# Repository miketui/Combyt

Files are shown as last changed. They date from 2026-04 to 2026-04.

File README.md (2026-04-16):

# TAYLKOMB Modular Comb System — Combyt Repository

**Patent Pending:** USPTO #19362254  
**Principal Engineer / Founder:** Michael David Warren Jr. / TAYLKOMB LLC  
**Active Revision:** Rev D — Vertical Ball-Stud + Cross-Detent Architecture

---

## Repository Structure

```
Combyt/
│
├── scaffold/                    ← 🔧 WORKING CAD PIPELINE (start here)
│   ├── .mcp.json                   MCP server config (Claude Code)
│   ├── pyproject.toml              Python package definition
│   ├── src/taylkomb_mcp/           Server + CAD generation source
│   │   ├── server.py               MCP server (stdio + HTTP)
│   │   ├── server_logic.py         Tool implementations
│   │   ├── spec_models.py          Pydantic spec models (Rev C + D)
│   │   ├── validation.py           Rulepack validation + ranking
│   │   ├── spec_guard.py           Locked datum guard
│   │   ├── cad/
│   │   │   ├── parts.py            Rev D part generators (6 parts)
│   │   │   ├── locking_module.py   Ball-stud + socket geometry
│   │   │   ├── comb_blank.py       Comb silhouette + M-cutout
│   │   │   ├── connector_common.py Shared CAD helpers
│   │   │   ├── combs.py            Phase 2 comb geometry
│   │   │   ├── handles.py          Phase 2 handle geometry
│   │   │   └── assemblies.py       Comb+handle assembly
│   │   └── ...
│   ├── specs/
│   │   ├── taylkomb_revD_master.json    ← ACTIVE SPEC
│   │   ├── taylkomb_revC_master.json    (retired, reference only)
│   │   └── variant_sweeps/
│   │       ├── sweep_A.json             Tight tolerance
│   │       ├── sweep_B.json             Nominal
│   │       └── sweep_C.json             Loose tolerance
│   ├── agent/policies/
│   │   ├── locked_datums.json       NEVER edit without human approval
│   │   └── pass_fail_rules.json     Validation thresholds
│   ├── tests/
│   └── scripts/
│
├── output/                      ← 📦 GENERATED CAD FILES (use these)
│   └── sweep_a/
│       ├── SWEEP_A_SUMMARY.md       Full results report
│       ├── step/                    ← STEP files for manufacturing / CAD import
│       ├── stl/                     ← STL files for 3D printing / preview
│       ├── reports/                 Per-variant markdown reports
│       ├── metrics/                 Measurements + validation JSONs
│       └── release_packs/           Zipped release bundles per variant
│
├── reference/                   ← 📐 ORIGINAL / LEGACY FILES
│   ├── original_cad/
│   │   ├── step/                TC-001 through TH-003 (Rev C originals)
│   │   ├── stl/                 Original mesh exports
│   │   └── pdf/                 (empty, PDFs in docs/)
│   ├── revD_samples/            Early Rev D stem + comb samples
│   └── patches/                 Scaffold + patch zip archives
│
├── docs/                        ← 📄 DOCUMENTATION
│   ├── design_plans/            Rev D plan, PRD, prompts, audits
│   ├── engineering_studies/     Size/weight/ergonomics studies
│   ├── pdfs/                    Per-part drawing PDFs
│   └── images/                  Photos, renders
│
└── README.md                    ← You are here
```

---

## Which files do I use?

### For manufacturing / CAD review
→ **`output/sweep_a/step/`** — these are the latest Rev D STEP files, validated against the rulepack.

| File | Part | OAL | Mass |
|---|---|-----|---|
| `main_comb_A_main_01.step` | Main comb (mixed teeth) | 202 mm | 13.7 g |
| `wide_comb_A_wide_01.step` | Wide-tooth comb | 178 mm | 12.5 g |
| `narrow_comb_A_narrow_01.step` | Narrow-tooth comb | 178 mm | 10.7 g |
| `round_handle_A_round_01.step` | Round tail handle | 165.5 mm | 14.5 g |
| `flat_handle_A_flat_01.step` | Flat handle | 172.5 mm | 30.7 g |
| `double_handle_A_double_01.step` | Double-prong fork | 158 mm | 49.4 g |

### For 3D printing / quick preview
→ **`output/sweep_a/stl/`** — same parts as above, triangulated mesh format.

### For comparison to original designs
→ **`reference/original_cad/step/`** — Rev C originals (TC-001, TC-002, TC-003, TH-001, TH-002, TH-003). **These are retired.**

### When you run a new sweep
New files will appear in `output/sweep_b/`, `output/sweep_c/`, etc. — same subfolder structure.

---

## Quick Start — Run the Pipeline

```bash
cd scaffold
python -m venv .venv && source .venv/bin/activate
pip install -e .

# Verify MCP server
python -m taylkomb_mcp.server --transport stdio

# Or run HTTP for remote access
python -m taylkomb_mcp.server --transport streamable-http --port 3333
```

Then use Claude Code or call the MCP tools directly.

---

## Locked Datums (DO NOT CHANGE without human approval)

| Datum | Value |
|---|---|
| Comb silhouette | 32.0 × 6.7 mm |
| M-cutout | 36.0 peak-to-peak × 18.0 depth |
| Socket | Ø 4.10 × 13.0 mm |
| Stem | Ø 4.00 × 14.0 mm, D-profile chord 3.20 |
| Ball head | Ø 5.00, groove Ø 3.20 |
| Seam step max | 0.10 mm |

---

## Architecture

Rev D: **Vertical ball-stud + spring cross-detent with D-profile anti-rotation.**  
Rev C (horizontal dovetail) is retired.  
Bayonet, collet, magnet variants are ruled out.

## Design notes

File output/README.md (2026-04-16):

# Output — Generated CAD Files

This folder contains CAD files generated by the TAYLKOMB MCP pipeline.  
**Always use files from here** — never from `reference/`.

## Folder Convention

Each sweep gets its own subfolder:

```
output/
├── sweep_a/          ← Tight tolerance (current)
│   ├── step/         ← STEP files — use for manufacturing & CAD import
│   ├── stl/          ← STL files — use for 3D printing & preview
│   ├── reports/      ← Per-variant markdown reports
│   ├── metrics/      ← Measurement + validation JSONs
│   └── release_packs/← Zipped bundles (STEP+STL+report+metrics)
├── sweep_b/          ← Nominal tolerance (future)
└── sweep_c/          ← Loose tolerance (future)
```

## File Naming

Format: `{part_name}_{variant_id}.{ext}`

Example: `main_comb_A_main_01.step`
- Part: `main_comb`
- Sweep: `A` (tight)
- Variant number: `01`

## Which file to use?

| If you need... | Use this |
|---|---|
| Import into Fusion/SolidWorks/FreeCAD | `step/*.step` |
| 3D print a test piece | `stl/*.stl` |
| Check if a variant passed validation | `metrics/*_validation.json` |
| See bounding box / mass / dimensions | `metrics/*_metrics.json` |
| Human-readable summary | `reports/*_report.md` |
| Send everything to a manufacturer | `release_packs/*_release.zip` |

## Current Sweep A Results (6/6 PASS)

See `SWEEP_A_SUMMARY.md` for full details.

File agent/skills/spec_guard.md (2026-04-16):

# Skill — Spec Guard

Purpose:
Protect TAYLKOMB locked datums and system invariants.

Rules:
- Treat `locked_datums` as non-editable.
- Reject requests that change the connector standard unless the spec explicitly unlocks them.
- Always compare proposed overrides against the master spec before geometry generation.

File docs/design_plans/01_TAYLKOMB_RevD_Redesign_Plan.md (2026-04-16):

# TAYLKOMB — Rev D CAD Redesign Plan
**Locking Mechanism Overhaul + Six-Part Geometry — grounded in new render intent + 2026 pro-comb benchmarks**
Michael David Warren Jr. / TAYLKOMB LLC — Patent Pending USPTO #19362254
Date: April 16, 2026

---

## 0. Why this is Rev D (not Rev C)

Rev C assumed a **horizontal dovetail** — the handle slid onto the comb's side like a tongue-and-groove. The new renders (`Black_Combs.png`, `Metal_Agents.png`) + the new STL files you uploaded this session show a fundamentally different architecture:

1. **The Main Comb is the receiver.** It has the carved "M-shaped" dorsal cutout on its spine and **no downward stem**.
2. **The other 5 parts (2 combs + 3 handles) each carry the male stem** that inserts into the Main Comb. This is visible in the renders — Narrow and Wide combs have a thin stem extending *down* from their lower corner; all three handles have a small connector block with a thin pin above it.
3. **Insertion axis is vertical (along the comb's long axis), not lateral.** The stem slides into a socket cut into the Main Comb's spine cutout.

That's a Rev D architecture, not a tweak to Rev C. The locking mechanism has to be rebuilt around it. **Disregard the old STEP files** per your direction — they are work-in-progress snapshots, kept for history only.

---

## 1. Benchmark grounding (2026, web-verified)

| Product | OAL | Width | Source |
|---|---:|---:|---|
| Sam Villa Signature Long Cutting Comb | **222.25 mm** (8.75″) | 31.75 mm (1.25″) | saloncentric.com |
| Sam Villa Signature Short Cutting Comb | **200.03 mm** (7.875″) | 31.75 mm (1.25″) | saloncentric.com |
| Y.S. Park cutting combs | **165–188 mm** (6.5–7.4″) | — | staysharpshears.com |
| Y.S. Park 339 cutting | 229 mm | — | ysparkusa.com (prior research) |

**Your current STL target envelope (converted from inches):**

| Part | STL OAL (mm) | STL width (mm) | Verdict vs. benchmarks |
|---|---:|---:|---|
| Comb_Main | 145.3 | 32.3 | Width ✅ matches pro 1.25″ | OAL 20–55 mm under pro band |
| Comb_Narrow | 177.6 | 32.3 | Width ✅ | OAL in Y.S. Park band |
| Comb_Wide | 177.6 | 32.3 | Width ✅ | OAL in Y.S. Park band |
| Round_Handle | 154.2 | 10.2 × 5.1 | Ultra-slender stem (not full grip) |
| Flat_Handle | 162.4 | 10.2 × 5.1 | Ultra-slender stem |
| Double_Handle | 154.2 | 17.3 × 5.1 | Fork stem |

The slender handles are a **deliberate aesthetic choice** — the renders show handles designed as *continuations* of the comb line, not traditional bulk grips. That's a valid premium position ("instrument-like" rather than "tool-like"). The width of 10.16 × 5.08 mm = exactly 0.4″ × 0.2″ = a clean inch-based rail stock. Keep it.

---

## 2. Locking mechanism — Rev D design

### 2.1 Architecture

**Receiver**: Main Comb
**Driver**: any of the 5 non-Main parts (Wide Comb, Narrow Comb, Round Handle, Flat Handle, Double Handle)
**Insertion axis**: vertical, along the comb long axis (part slides *up* into the Main Comb socket)
**Lock type**: **captive ball-stud + spring-loaded cross-detent**, releasable via a flush side button on the Main Comb

### 2.2 Why this architecture (and why not Rev C's horizontal dovetail)

| Consideration | Rev C horizontal dovetail | Rev D vertical ball-stud |
|---|---|---|
| Matches render intent | ❌ render shows vertical stem | ✅ |
| Hair-catch at seam | Medium (two long rail edges exposed) | Low (single circular seam, hidden in spine cutout) |
| Manufacturing in PPS-CF40 | Dovetail walls are a mold risk at 60° undercut | Straight bore is trivial |
| Manufacturing in 316L stainless for stem | CNC dovetail tolerance is tight (±0.02) | Turn + drill on a Swiss CNC, routine |
| Cycle life to 15 000 swaps | Dovetail edges chip over time in CF-filled resin | Ball-on-bore wear is a solved problem (Quik-Latch: 150 lb pull rating, QL-25) |
| Part count | 1 comb side + 1 handle side (machined features) | 1 comb side (spring + button + ball) + 1 handle side (turned stem with groove) |
| Visual language | Two parting lines visible | One near-invisible circular joint |

Ball-stud captive latches are a mature, mass-produced pattern — Quik-Latch QL-25 at 31.72 mm diameter withstands 150 lb (≈667 N) pull before failure. **Scaling the pattern down to a 4 mm stud still buys 20–40 N working retention, which is 2–4× the 8–12 N detent force Rev C specified.**

### 2.3 Canonical dimensions (Rev D, locked)

```
REV D LOCKING MODULE — canonical geometry (all dimensions mm)
─────────────────────────────────────────────────────────────
DRIVER SIDE (on the 5 non-Main parts)
  Stem outer diameter ................  4.00 ±0.03
  Stem length (above connector block)  14.00 (full engagement = 12 into socket)
  Ball-head diameter (stem tip) ......  5.00
  Ball-head retention groove .........  Ø 3.20 × 1.00 long, 0.40 below ball-head
  Stem root fillet ...................  R 0.80
  Connector block (on stem base) .....  10.0 × 5.0 × 5.0 (W × H × D)
                                         → flush to part body, hair-shed chamfer 0.5 × 45°
  Material (stem + ball) .............. 316L stainless (turned, 1-pc)
  Surface finish ...................... Ra ≤ 0.4 µm on stem OD

RECEIVER SIDE (on the Main Comb only)
  Socket bore diameter ...............  4.10 (stem slip fit, 0.05 clearance per side)
  Socket bore depth ..................  13.00 (1 mm bottom clearance)
  Ball-capture cross-bore ............. Ø 3.00, perpendicular to socket axis
  Ball-capture ball diameter .........  3.00, 316L
  Ball spring ........................ 302 SS compression, 8–12 N at engagement
  Spring bore length .................  8.0 (Carr Lane CL-6-BPN or equivalent)
  Release-button bore diameter .......  6.00, flush to comb spine
  Release-button travel ..............  0.8 (enough to clear ball from stem groove)
  Release-button protrusion (unpressed) 0.3 above comb spine
  Socket wall thickness around bore ..  2.0 (sufficient for PPS-CF40 at 15k cycles)
  Material (ball plunger sub-assy) ... standard cross-drilled ball plunger,
                                        press-fit into molded PPS-CF40 socket
  Seam step (socket face to driver)...  ≤ 0.10 (tighter than Rev C's 0.15)
  Lead-in chamfer on socket mouth ....  30° × 0.8
  Hair-shed chamfer on seam perimeter.  0.5 × 45°

SYSTEM
  Insertion motion ................... pure axial (vertical), zero rotation
  Insertion force .................... 10–15 N (ball riding over stem ramp)
  Retention force .................... 30–40 N (ball in groove, locked)
  Release force ...................... 1–2 N (button press)
  Audible feedback ................... tactile + audible "click" on groove seat
  Cycle life target .................. ≥ 15 000 swaps
```

### 2.4 Anti-rotation (important because a round stem can spin)

The stem is circular, so an *anti-rotation key* is mandatory. Two options — pick one and lock:

**Option A (recommended): D-profile stem.** Flatten one side of the 4.00 mm stem to 3.20 mm across the chord. Socket gets matching D-bore. Zero rotation, single-orientation insertion (forces correct comb-side-up assembly, which is a UX bonus). Machinable in one Swiss-CNC op.

**Option B: 1.5 × 1.5 mm anti-rotation key on stem base**, mating to a relief in the socket mouth. More parts, more edges. Not recommended.

**Rev D locks Option A (D-profile).**

### 2.5 Release geometry

Release button sits on the **left face** of the Main Comb's spine cutout (when held teeth-down, spine-up, in the right hand). Thumb-accessible. Flush 0.3 mm protrusion. Press to release, ball retracts 0.8 mm, pull driver out axially.

### 2.6 Why this is better than Rev C's architecture

- **Hair cannot catch.** The entire joint is inside the Main Comb's M-cutout, not on an exposed rail edge.
- **One machining op per stem** (turn + groove + chord-flat on a Swiss CNC).
- **Molded socket is a straight bore**, not a 60° dovetail. PPS-CF40 molds cleanly with no side-action tooling.
- **Release action is pure 1-D press**, not the 2-D slide Rev C required.
- **Higher retention** (30–40 N vs. Rev C's 8–12 N) without the insertion force going up (because the ball rides a lead-in ramp on the stem).

---

## 3. Per-part redesign (Rev D)

Sources in order of precedence: **render intent** → **new STL measurements** → **Rev C dimensional ranges** → **2026 pro benchmarks**.

### 3.1 Main Comb (receiver — no stem)

| Parameter | Current STL (mm) | Rev D target (mm) | Rationale |
|---|---:|---:|---|
| OAL | 145.29 | **198 – 205**, target 202 | Pro "short cutting" band; Sam Villa Short = 200 |
| Width (spine height incl. M-cutout) | 32.26 | **32.0** | Matches 1.25″ pro standard; keep |
| Body thickness | 6.69 | **6.5 – 7.0**, target 6.7 | Matches current; within pro band |
| Tooth region length | — derived | ~140 | ~70% of OAL |
| M-cutout depth (from spine top) | — | **18.0** | Ergonomic index-finger rest |
| M-cutout peak-to-peak | — | **36.0** | Centered on comb |
| Socket bore position | — | Center of M-cutout valley | One socket only, inside the cutout |
| Socket bore (receiver) | — | Ø 4.10 × 13.0 deep, D-profile | Rev D locking module |
| Ball-capture sub-assembly | — | Ø 3.0 ball, 302 SS spring, 8–12 N | Rev D locking module |
| Release button protrusion | — | 0.3 above spine | Flush, thumb-operated |
| Material | — | **PPS-CF40** (injection mold) | Locked per Rev C §5 |
| Mass target | — | **12 – 18 g** | PPS-CF40 × 22.7 cm³ ≈ 13 g (from STL vol) |

### 3.2 Narrow Comb (driver — stem down)

| Parameter | Current STL (mm) | Rev D target (mm) | Rationale |
|---|---:|---:|---|
| OAL (body only, excl. stem) | 177.55 | **178** | Matches STL; Y.S. Park cutting band |
| Width | 32.26 | **32.0** | Shared spine silhouette with Main |
| Thickness | 6.69 | **6.7** | Shared |
| Tooth pitch (narrow) | — | **1.8 – 2.2**, target 2.0 | Fine cutting comb standard |
| Tooth row count | — | **60 teeth** @ 2.0 mm pitch over 120 mm | — |
| Stem (driver) | — | Ø 4.00 D-profile × 14 long, ball-head 5.0, groove per §2.3 | Rev D locking module |
| Stem position | — | Center of comb body lower edge | Axial alignment with Main's socket |
| Material | — | **PPS-CF40** + 316L stainless stem (insert-molded or pressed-in) | PPS-CF40 won't survive 15 k cycles as a bare stem |
| Mass target | — | **10 – 14 g** | Body 9.3 cm³ PPS-CF40 ≈ 13 g + 1 g stem |

### 3.3 Wide Comb (driver — stem down)

| Parameter | Current STL | Rev D target | Rationale |
|---|---:|---:|---|
| OAL (body only) | 177.55 | **178** | Same silhouette as Narrow |
| Width | 32.26 | **32.0** | Shared |
| Thickness | 6.69 | **6.7** | Shared |
| Tooth pitch (wide) | — | **4.5 – 5.5**, target 5.0 | Detangling band |
| Tooth row count | — | **24 teeth** @ 5.0 mm pitch over 120 mm | — |
| Stem | — | Same Rev D module as Narrow | Interchangeable |
| Material | — | PPS-CF40 + stainless stem | Same |
| Mass target | — | **11 – 15 g** | Slightly heavier (more material between wider teeth) |

### 3.4 Round Handle (driver — stem up, taper down)

| Parameter | Current STL | Rev D target | Rationale |
|---|---:|---:|---|
| OAL (total, incl. stem) | 154.18 | **158** | Render shows slender tail; keep |
| Body cross-section at connector block | 10.16 × 5.08 | **10.0 × 5.0** | Matches render; clean inch stock |
| Body cross-section at tip | — | **Ø 2.3** | Rev C §8 priority 6 — precision parting |
| Taper transition | — | Smooth spline from rect 10×5 → round Ø 2.3 over 130 mm | — |
| Connector block (base of stem) | — | 10.0 × 5.0 × 5.0, flush to body | Rev D module |
| Stem | — | Rev D driver module (see §2.3) | — |
| Material | — | **316L stainless** (CNC turned from bar) | Solid now that the body is so slender; hollowing buys <2 g |
| Mass target | — | **10 – 14 g** | Vol 1.46 cm³ × 7.98 ≈ 11.6 g per current STL |

### 3.5 Flat Handle (driver — stem up, flat tail)

| Parameter | Current STL | Rev D target | Rationale |
|---|---:|---:|---|
| OAL | 162.41 | **165** | Keep close to STL |
| Cross-section | 10.16 × 5.08 | **10.0 × 5.0** | Flat-rectangular stock |
| Tail profile | flat | radiused tip, 5.0 × 10.0 section constant, rounded end | Render-verified |
| Connector block + stem | — | Rev D driver module | — |
| Material | — | 316L stainless (CNC from flat bar) | — |
| Mass target | — | **20 – 25 g** | Vol 2.84 cm³ × 7.98 ≈ 22.7 g |

### 3.6 Double Handle (driver — stem up, fork down)

| Parameter | Current STL | Rev D target | Rationale |
|---|---:|---:|---|
| OAL | 154.18 | **158** | — |
| Fork outer width | 17.27 | **18.0** | Slightly widen for stability |
| Fork thickness (each prong) | 5.08 | **5.0** | — |
| Fork inner gap | ~8.0 derived | **8.0** | Parts for sectioning |
| Fork root fillet | — | **R 1.5** | Fatigue — Rev C audit finding |
| Fork length (working) | ~130 | **125** | Keeps tip OAL at 158 |
| Connector block + stem | — | Rev D driver module | — |
| Material | — | 316L stainless (CNC or wire-cut from plate, weld-free one-piece preferred) | — |
| Mass target | — | **22 – 28 g** | STL shows current weight high because fork walls are currently thicker than needed; target is lighter |

---

## 4. Shared spine silhouette (renders confirm)

All three combs (Main, Narrow, Wide) share the same outer silhouette including the M-cutout. Differences are **only in the tooth field**:

- Main: mixed tooth pattern (fine-left, wide-right), plus a pick tip on the left end
- Narrow: 2.0 mm uniform pitch
- Wide: 5.0 mm uniform pitch

This simplifies the CAD agent enormously: **build one `comb_body_blank.py` that generates the shared silhouette + M-cutout, then a second function `apply_tooth_field(blank, pitch, count)` that stamps teeth.**

---

## 5. Assembly envelope (Rev D, recomputed)

With the vertical-insert architecture, the assembled length is **Main OAL + driver OAL − engagement depth**:

| Config | Main OAL | Driver OAL | Engagement | Assembled OAL |
|---|---:|---:|---:|---:|
| Main + Narrow | 202 | 178 | 12 | **368** |
| Main + Wide | 202 | 178 | 12 | **368** |
| Main + Round Handle | 202 | 158 | 12 | **348** |
| Main + Flat Handle | 202 | 165 | 12 | **355** |
| Main + Double Handle | 202 | 158 | 12 | **348** |

**Observation.** Rev C's 280–320 mm assembled target is **still not achievable** with this architecture because the Main Comb alone is already 202 mm — you cannot assemble into the 280 mm band unless the driver is 90 mm or less, which defeats the modular purpose.

**Decision surfaced for human input.** Two options:

- **A)** Accept **340–380 mm** as the Rev D assembled band. This matches Mason Pearson combo brushes and full-length pro cutting tools; stylists consider this professional, not long.
- **B)** Shrink Main Comb further to **160 mm** (Y.S. Park short band) to hit 300–340 mm assembled. Reduces effective tooth field by ~25%, hurts the cutting role.

**Rev D recommendation: A.** The "modular long-tool" identity is stronger than forcing the 280–320 band, and the render intent clearly shows longer, slender silhouettes. The agent's rulepack will reflect this — but flag as a WARN until you sign off.

---

## 6. Weight envelope (Rev D)

| Part | Material | Target (g) | Max (g) |
|---|---|---:|---:|
| Main Comb | PPS-CF40 + ball plunger sub-assy (~2 g) | 14–18 | 22 |
| Wide Comb | PPS-CF40 + 316L stem | 11–15 | 18 |
| Narrow Comb | PPS-CF40 + 316L stem | 10–14 | 17 |
| Round Handle | 316L (solid) | 10–14 | 17 |
| Flat Handle | 316L (solid) | 20–25 | 30 |
| Double Handle | 316L (solid one-piece fork) | 22–28 | 34 |
| **Assembled (Main + any driver)** | — | **26–46 g** | **56 g** |

The Rev D assembled weight is **lighter than Rev C's 40–58 g** because (a) the new handle silhouettes are much slimmer and (b) hollowing is no longer required to hit weight. That's a net win.

---

## 7. Rev D revision checklist (priority order)

| # | Task | Part(s) | Urgency |
|---|---|---|---|
| 1 | Implement Rev D locking module: socket + ball-plunger sub-assy + D-stem | All 6 | IMMEDIATE |
| 2 | Regenerate shared comb-silhouette blank with M-cutout | Main, Wide, Narrow | IMMEDIATE |
| 3 | Apply differentiated tooth fields (mixed / narrow / wide) | Main, Narrow, Wide | IMMEDIATE |
| 4 | Model slender handle silhouettes per render intent | Round, Flat, Double | IMMEDIATE |
| 5 | Add flush release button on Main Comb spine face | Main | IMMEDIATE |
| 6 | Add hair-shed chamfer (0.5 × 45°) at seam perimeters | All 6 | NEXT |
| 7 | Round handle tail taper → Ø 2.3 mm tip | Round | NEXT |
| 8 | Double handle fork-root R1.5 fillet | Double | NEXT |
| 9 | Grip microtexture / knurling zone on handles | All 3 handles | PRE-PROTO |
| 10 | Final draft angles ≥ 0.5° on all molded PPS-CF40 surfaces | All 3 combs | PRE-PROTO |

---

## 8. Validation gates (Rev D rulepack additions)

In addition to the Rev C rules, Rev D adds:

1. `stem_diameter_mm == 4.00 ± 0.03` — locked.
2. `socket_bore_diameter_mm == 4.10 ± 0.03` — locked.
3. `stem_ball_head_diameter_mm == 5.00 ± 0.05` — locked.
4. `stem_d_profile_chord_mm == 3.20 ± 0.05` — locked.
5. `insertion_force_N ∈ [10, 15]` — design simulation + physical.
6. `retention_force_N ∈ [30, 40]` — must exceed 3× expected pull in use.
7. `release_force_N ∈ [1, 2]` — thumb-comfortable.
8. `seam_step_mm ≤ 0.10` — tightened from Rev C's 0.15.
9. `cycle_life_target ≥ 15 000` — verified in prototype phase 2.
10. **Assembled-length rule REPLACED**: new band is `assembled_oal_mm ∈ [340, 380]` (WARN outside, REJECT below 320 or above 410).

---

## 9. Export / artifact policy (unchanged from Rev C)

Every variant emits: `.py` (CadQuery source), `.step` (AP214), `.stl` (binary), `.3mf` (optional), `.png` (iso + seam close-up), `_metrics.json`, `_validation.json`, `_report.md`. Release bundle zips the passing set.

---

## 10. What the agent must still NEVER do

- Touch the locked Rev D socket / stem geometry without a human-edited spec bump.
- Export a STEP for a variant that failed any rulepack rule.
- Propose alternatives to the ball-stud + cross-detent architecture (dovetail, bayonet, magnet, collet are ruled out — Rev C §6.3 + Rev D §2.2).
- Average conflicting numbers. Source precedence: render intent → new STL → Rev C → benchmarks.

---

*End — Deliverable 1 (Rev D).*

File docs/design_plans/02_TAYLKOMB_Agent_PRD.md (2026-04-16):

# TAYLKOMB CAD Agent — Product Requirements Document (Rev D)
**Locking mechanism overhaul + full parametric pipeline**
Owner: Michael David Warren Jr. / TAYLKOMB LLC
Date: April 16, 2026

---

## 1. Problem statement

TAYLKOMB's six-part modular comb system moved from Rev C (horizontal dovetail) to **Rev D (vertical ball-stud + cross-detent)** based on new render intent and current render-verified STL geometry. The old STEP files are obsolete. Manual CAD rework for every parameter sweep across 6 parts (Main Comb + 2 comb drivers + 3 handle drivers) is too slow and loses the locked-datum guarantee needed for interchangeability.

**Goal.** Build a Claude-powered CAD agent that regenerates any of the six parts from a Rev D master spec, applies controlled sweeps, validates every variant against a deterministic rulepack, and produces manufacturer-ready STEP/STL/report bundles — with zero drift on the locked socket/stem interface.

## 2. Recommended workflow (highest priority — read first)

This is the specific sequence of work I recommend you follow, with the tool for each stage.

### 2.1 Phased workflow

```
PHASE 0 — Environment stand-up (1 day)
  Tool: your laptop + VS Code + Terminal
  → Clone existing scaffold (taylkomb-cad-agent-scaffold.zip — you already have it)
  → Python venv + install CadQuery + MCP SDK + Pydantic
  → Install Claude Code CLI (Node)
  → Install claude-agent-sdk (Python) for scripted runs
  → `pytest` passes

PHASE 1 — Spec migration Rev C → Rev D (0.5 day)
  Tool: your text editor
  → Fork specs/taylkomb_revC_master.json → specs/taylkomb_revD_master.json
  → Replace connector section with Rev D socket + stem module (see Deliverable 1 §2.3)
  → Update agent/policies/locked_datums.json
  → Update agent/policies/pass_fail_rules.json with Rev D rules
  → `pytest` still passes (test_rulepack.py reads from rulepack, so it'll auto-update)

PHASE 2 — Geometry rebuild (2–3 days)
  Tool: Claude Code (local) running Opus 4.7 + Sonnet 4.6
  → Author a shared comb-silhouette-blank generator (M-cutout included)
  → Author the Rev D locking module (socket + stem families)
  → Author 6 part generators that compose blank + locking module + part-specific features
  → Each generator exports STEP + STL + PNG preview + metrics JSON
  → Rulepack validation on every output

PHASE 3 — Variant sweep + ranking (1 day)
  Tool: Claude Code with sweep files
  → Run sweep_A (tight fit), sweep_B (nominal), sweep_C (loose)
  → Compare 3 × 6 = 18 variants
  → Release pack the winners

PHASE 4 — Physical prototype (2 weeks)
  Tool: SLS-nylon print (FormLabs / i.Materialise / Shapeways) for combs,
        CNC 316L from a local machine shop for stem + handle
  → Fit check: assemble all 5 drivers into Main, cycle 100 swaps by hand
  → Measure seam step with feeler gauges
  → If fit is good, move to Phase 5

PHASE 5 — Agent Builder wiring (0.5 day, once Phase 4 lands)
  Tool: platform.claude.com Agent Builder
  → Expose local MCP server over Cloudflare Tunnel
  → Register as remote MCP in Agent Builder
  → Import Manager Agent prompt (Deliverable 4)
  → End-to-end test from web

PHASE 6 — Manufacturer handoff (ongoing)
  Tool: email / Slack + zipped release packs
  → Send STEP + STL + metrics + report to injection-mold vendor (combs)
  → Send STEP + DXF + tolerance block to Swiss CNC shop (stems + handles)
  → Coordinate ball-plunger sub-assy sourcing (Carr Lane CL-6-BPN or equivalent)
```

### 2.2 Workflow rationale — why this order

1. **Spec before geometry.** Rev D is a real architecture change. Lock the spec first or you'll rewrite geometry twice.
2. **Shared comb blank before individual parts.** Three comb heads share the silhouette; writing it once saves ~60% of the CAD time.
3. **Claude Code local before Agent Builder remote.** Debugging geometry generation works much better against local files with stdio MCP. Once it's stable, flip to remote.
4. **SLS-nylon prototypes before PPS-CF40 molds.** PPS-CF40 molding requires tooling ($30–80k). Nylon SLS ($15–30 per part) proves the locking mechanism, then you commit to tooling.
5. **Manager Agent last.** The web agent is the user-facing convenience layer. Don't build it until the Claude Code pipeline is proven.

## 3. Users

| User | Goal | Access |
|---|---|---|
| **Principal (Michael, TAYLKOMB LLC)** | Drive iteration, approve releases, edit specs. | Agent Builder (web) for day-to-day; Claude Code for deep work |
| **CAD contractor / engineer** | Generate variants, inspect STEPs, run prototypes. | Claude Code |
| **Manufacturer / MIM vendor** | Receive release packs. | Zipped bundle only |

## 4. Success metrics

| Metric | Target | Measurement |
|---|---|---|
| Spec edit → validated STEP for 1 part | ≤ 90 s | `generate_connector_variant` wall clock |
| Locked-datum drift events | 0 | Spec Guard audit every run |
| False-pass rate (CAD passes, prototype fails) | < 5% | Prototype QA vs. validator verdict |
| Variants evaluated per session | ≥ 18 (= 3 sweeps × 6 parts) | Release log |
| Full-family rebuild (6 parts) | ≤ 15 min end-to-end | CLI `run-all` timer |
| Insertion force accuracy (CAD vs. actual) | ±20% | Prototype instrumented test |

## 5. Functional requirements

- **F1** — Load Rev D master spec into validated Pydantic model.
- **F2** — Generate CadQuery solid for any of 6 parts + optional overrides.
- **F3** — Enforce locked datums (socket geometry, stem geometry, comb silhouette).
- **F4** — Export STEP + STL + 3MF + PNG preview.
- **F5** — Measure bounding box, volume, mass, insertion force est., retention force est., seam step, tip diameter, fork geometry.
- **F6** — Validate against `pass_fail_rules.json`.
- **F7** — Rank variants by pass then proximity-to-target.
- **F8** — Export release pack zip.
- **F9** — Run sweep files in batch.
- **F10** — Refuse STEP export on failed variants (unless human `--force` logged).

## 6. Non-functional requirements

- **NF1** — Determinism: same spec + overrides → byte-identical STEP.
- **NF2** — Auditability: every run emits `.md` + `.json` report.
- **NF3** — No network required for geometry (pure local).
- **NF4** — Pinned versions in `pyproject.toml`.
- **NF5** — MCP server works under both stdio (Claude Code) and streamable-http (Agent Builder).
- **NF6** — Model routing: Opus 4.7 orchestration, Sonnet 4.6 worker, Haiku 4.5 quick checks.

## 7. System architecture

```
┌──────────────────────────────────────────────────────────────────┐
│  MANAGER AGENT  (Claude Opus 4.7, platform.claude.com)           │
│  — accepts natural-language task                                 │
│  — writes/edits the JSON spec (via human approval)               │
│  — dispatches to Claude Code worker via MCP-over-HTTP            │
│  — surfaces validation reports + release packs                   │
└──────────────────────────┬───────────────────────────────────────┘
                           │ MCP (streamable-http via Cloudflare Tunnel)
                           ▼
┌──────────────────────────────────────────────────────────────────┐
│  CLAUDE CODE ORCHESTRATOR  (Claude Opus 4.7, local)              │
│  — reads spec + policies                                         │
│  — decides part order + sweep                                    │
│  — calls MCP tools, never bypasses them                          │
└───┬────────────────────┬─────────────────────────────┬───────────┘
    ▼                    ▼                             ▼
┌──────────┐      ┌──────────────┐           ┌────────────────────┐
│ Geometry │      │ Deterministic│           │ DFM Reviewer       │
│ Author   │      │ Validator    │           │ (Sonnet 4.6 +      │
│ (Sonnet  │      │ (Python only │           │  rulepack)         │
│  4.6 +   │      │  — no LLM)   │           │                    │
│ CadQuery)│      │              │           │                    │
└──────────┘      └──────────────┘           └────────────────────┘
    │                    │                             │
    ▼                    ▼                             ▼
    data/generated · data/exports · data/previews · data/reports
```

## 8. Recommended tool / API stack

### 8.1 Must install locally (all free unless noted)

| Tool | Purpose | Install | Cost |
|---|---|---|---:|
| Python 3.11+ | Runtime | system | — |
| Node 20+ | Claude Code CLI | system | — |
| **CadQuery 2.5.2+** | Primary code-to-CAD (BREP via OpenCascade/OCP) | `pip install cadquery` | free |
| **build123d** (optional fallback) | Secondary backend | `pip install build123d` | free |
| **MCP SDK (Python)** | MCP server runtime | `pip install "mcp[cli]"` | free |
| **Pydantic 2.x** | Spec validation | `pip install pydantic` | free |
| **Typer + Rich** | CLI + pretty output | `pip install typer rich` | free |
| **trimesh** | STL inspection | `pip install trimesh` | free |
| **claude-agent-sdk** | Python scripted orchestration | `pip install claude-agent-sdk` | free |
| **@anthropic-ai/claude-code** | Local agent harness | `npm i -g @anthropic-ai/claude-code` | free |
| **pytest** | Tests | `pip install pytest` | free |

### 8.2 Must sign up for

| Service | Purpose | Action | Cost |
|---|---|---|---:|
| **Anthropic API key** | Opus 4.7 / Sonnet 4.6 / Haiku 4.5 | console.anthropic.com → API Keys → set `ANTHROPIC_API_KEY` | usage-based |
| **Anthropic Agent Builder** | Manager Agent hosting | console.anthropic.com → Agents → New | usage-based |
| **Cloudflare Tunnel** | Expose local MCP over HTTPS | `cloudflared tunnel` or `brew install cloudflared` | free tier |
| **GitHub private repo** | Version the agent + specs | `taylkomb-cad-agent` | free |
| **FreeCAD** (free, open-source) | Human visual QA of STEPs | freecad.org | free |
| **OnShape** (free personal) | Optional 2nd QA tool | onshape.com | free personal |

### 8.3 Monthly cost estimate (dev phase)

| Line | Estimate |
|---|---:|
| Anthropic API (Opus 4.7 orch + Sonnet 4.6 worker, ~5M input + 500k output tokens/mo) | $40 – $90 |
| Cloudflare Tunnel | $0 |
| GitHub | $0 |
| Visual QA tools | $0 |
| **Total dev-phase** | **~$40 – $90 / mo** |

Production phase adds only outbound STEP transfer to manufacturers — negligible.

### 8.4 Sourcing BOM (parts you need to buy for prototypes)

| Item | Spec | Vendor | Est. price |
|---|---|---|---:|
| Ball plunger (stainless, 3 mm ball, 8–12 N) | Carr Lane CL-6-BPN or Vlier SVB51 | carrlane.com / mcmaster.com | $6–10 ea |
| 316L 4 mm round bar (for stems) | 1m length | McMaster 89095K47 or local | $8–15 |
| 316L 10 × 5 mm flat bar (for handles) | 1m length | McMaster 6528K52 or local | $15–25 |
| SLS nylon comb prototype | 3 combs, 1 each | i.Materialise / Shapeways | $60–120 |
| CNC stem + handle prototype | 3 handles, 1 each | local Swiss CNC shop | $150–400 for 3 |
| Injection-mold tool (production only) | PPS-CF40 3-cav mold | offshore mold-maker | $18k–40k |

## 9. MCP tool contracts (locked)

| Tool | Inputs | Outputs | Locked behavior |
|---|---|---|---|
| `generate_connector_variant` | `spec_path`, `variant_id`, `part_name`, `backend`, `overrides`, `output_formats` | `{exports, metrics_path, validation_path, report_path, metrics, validation}` | Spec Guard blocks overrides on locked keys |
| `measure_geometry` | `model_path`, `checks[]` | measurement dict | Pure measurement |
| `validate_connector_rules` | `spec_path`, `measurement_path`, `part_name` | `{passed, checks, failures}` | Rulepack-only |
| `compare_variants` | `variant_records[]` | `{ranked, winner}` | Pass-first sort |
| `export_release_pack` | `variant_id`, `include[]` | `{archive_path, files}` | Refuses failed variants |

## 10. Data contracts

- `specs/taylkomb_revD_master.json` — source of truth (Rev D).
- `specs/variant_sweeps/sweep_{A,B,C}.json` — controlled sweeps.
- `agent/policies/locked_datums.json` — locked-key list.
- `agent/policies/pass_fail_rules.json` — rulepack.

All files are Pydantic-validated on load.

## 11. Milestones (aligned with §2.1 workflow)

| M | Deliverable | ETA |
|---|---|---|
| M0 | Scaffold stand-up, tests pass | Day 1 |
| M1 | Rev D spec merged, rulepack updated | Day 2 |
| M2 | Shared comb blank + locking module generate + validate | Day 4 |
| M3 | All 6 parts generate + validate at Rev D targets | Day 6 |
| M4 | 3 sweeps × 6 parts = 18 variants, ranked, release-packed | Day 7 |
| M5 | SLS nylon + CNC stem prototypes, physical fit check | Day 21 |
| M6 | Agent Builder Manager Agent live on web | Day 23 |
| M7 | First manufacturer handoff (MIM or injection mold) | Day 30 |

## 12. Risks + mitigations

| Risk | Likelihood | Impact | Mitigation |
|---|---|---|---|
| LLM edits a locked datum | Med | High | Spec Guard + Pydantic + unit test |
| CadQuery version bump breaks geometry | Low | Med | Pin in `pyproject.toml` |
| Ball plunger wear on PPS-CF40 bore past 15k cycles | Med | High | Add optional 316L insert sleeve if wear > 0.05 mm |
| Assembled length > 380 mm rejected by user | Low | Med | Deliverable 1 §5 surfaces the decision explicitly |
| Manager Agent can't reach local MCP via Cloudflare Tunnel | Low | Low | Fallback: pure local Claude Code flow |
| PPS-CF40 molding requires 3-cav tooling = $30k+ upfront | Med | Med | Prototype in SLS nylon first; only commit tooling after fit proven |

## 13. Out of scope (v1)

- FEA / stress simulation (v2, via separate MCP tool)
- Mold-flow analysis (vendor-side in v1)
- Tooth pitch optimization beyond Rev D's locked ranges
- Any connector architecture other than Rev D ball-stud + cross-detent

---

*End — Deliverable 2 (Rev D).*

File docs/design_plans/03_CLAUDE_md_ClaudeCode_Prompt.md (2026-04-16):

# CLAUDE.md — TAYLKOMB CAD Agent (Rev D)

**This file IS the system prompt.** Claude Code auto-loads `CLAUDE.md` from the repo root as the agent's persistent context. Place this file at the root of `taylkomb-cad-agent/`. Do not edit sections marked LOCKED.

---

## 0. IDENTITY (LOCKED)

You are the **TAYLKOMB CAD Orchestrator**, operating locally under Claude Code for TAYLKOMB LLC (Michael David Warren Jr., Patent Pending USPTO #19362254).

- **Primary model (you, orchestrator):** `claude-opus-4-7` — fall back to `claude-opus-4-6` → `claude-sonnet-4-6` if the primary returns model-not-found.
- **Worker model** (repetitive CadQuery edits, report formatting, batch variant generation): `claude-sonnet-4-6`.
- **Quick-check model** (spec diffing, tag extraction): `claude-haiku-4-5`.

## 1. HARD GUARDRAILS (LOCKED — never violate)

1. **NEVER** modify locked datums. The Rev D socket (Ø 4.10 × 13.0), stem (Ø 4.00 × 14.0 D-profile, 5.0 ball-head, 3.20 groove), comb silhouette (32.0 × 6.7), and M-cutout (36.0 × 18.0) are system constants. If an override touches these, Spec Guard raises `SpecGuardError`. Do not route around it.
2. **NEVER** invent a new connector architecture. Rev D is **ball-stud + spring-loaded cross-detent with D-profile anti-rotation**. Bayonet, collet, magnetic, dovetail — all explicitly ruled out.
3. **NEVER** export a STEP for a failed variant. `export_release_pack` refuses; you do not force it.
4. **NEVER** execute bash or Python to edit CAD files outside the MCP tool surface.
5. **NEVER** claim a variant is manufacturing-ready without: (a) passing the rulepack AND (b) stating that physical prototyping is still required.
6. **NEVER** "average" conflicting numbers. Source precedence: Rev D master spec → render intent → new STL measurements → 2026 pro benchmarks.
7. **NEVER** edit `agent/policies/locked_datums.json` or `pass_fail_rules.json` yourself. Flag needed changes in a report.
8. **NEVER** use models other than the three listed in §0.

## 2. STACK (LOCKED)

- **Primary CAD backend:** CadQuery 2.5.2+ (Python / OpenCascade / OCP)
- **Fallback backend:** build123d (only when CadQuery cannot express a geometry)
- **Spec validation:** Pydantic 2.x
- **MCP transport:** stdio locally; streamable-http for remote Manager Agent
- **Density constants:** PPS-CF40 = 1.40e-3 g/mm³; 316L = 7.98e-3 g/mm³

## 3. MCP TOOL SURFACE (the only CAD actions you can take)

| Tool | Call when |
|---|---|
| `generate_connector_variant` | Build one part for one variant_id with overrides |
| `measure_geometry` | Read measurements from a generated variant |
| `validate_connector_rules` | Apply the rulepack to a metrics file |
| `compare_variants` | Rank a batch |
| `export_release_pack` | Zip a passing variant for hand-off |

**Resources** (read-only): `spec://taylkomb/rev-d`, `policy://taylkomb/locked-datums`.

## 4. STANDARD OPERATING PROCEDURE (LOCKED — execute in order, no branching)

### Step 1 — Orient
1. Read `specs/taylkomb_revD_master.json`.
2. Read `agent/policies/locked_datums.json` and `agent/policies/pass_fail_rules.json`.
3. Read the active sweep file under `specs/variant_sweeps/`.
4. Confirm `pytest -q` passes. If it fails, STOP and report.

### Step 2 — Plan
Produce a plan block containing:
- `variant_id` naming convention: `{sweep_tag}_{part_short}_{seq}` (e.g. `sweepA_round_01`).
- Part order: `main_comb → wide_comb → narrow_comb → round_handle → flat_handle → double_handle`.
- Overrides per part, drawn from the sweep file only.
- One-line rationale per override, tied to Rev D §.

### Step 3 — Generate
For each part, call:
```json
{
  "spec_path": "specs/taylkomb_revD_master.json",
  "variant_id": "<variant_id>",
  "part_name": "<part>",
  "backend": "cadquery",
  "overrides": { ... },
  "output_formats": ["step", "stl"]
}
```

### Step 4 — Measure
For each generated part, call:
```json
{
  "model_path": "<exports path from Step 3>",
  "checks": ["bounding_box", "mass_properties", "clearance_map", "seam_step", "tip_diameter", "fork_width", "stem_diameter", "socket_diameter", "insertion_force_est", "retention_force_est"]
}
```

### Step 5 — Validate
Call `validate_connector_rules` with `metrics_path` + `part_name`.
- `passed=true` → continue.
- `passed=false` → record failures, do NOT export release for that variant, move on.

### Step 6 — Compare
Once the whole sweep is built, call `compare_variants` with every record. Output the ranked list. Do not pick a winner if the top-ranked variant has any failure.

### Step 7 — Release
For each variant that passed Step 5, call:
```json
{
  "variant_id": "<variant_id>",
  "include": ["step", "stl", "source_py", "preview_png", "report_md", "json_metrics"]
}
```

### Step 8 — Summary
Write `data/reports/<sweep_tag>_summary.md` containing: plan, ranked list, release archive paths, "Human decision required" section for WARN-level issues, and a change-log entry (date, sweep tag, spec revision, variants generated, variants released).

## 5. REPORT CONVENTIONS (LOCKED)

- GitHub-flavored Markdown.
- All measurements mm, masses g, forces N.
- ISO 8601 dates (`YYYY-MM-DD`).
- Never quote code you did not just run; reference file paths.

## 6. IF YOU ARE STUCK (LOCKED)

1. Re-read spec and rulepack.
2. Trace the failing rule to its Rev D section in `docs/REV_D_PLAN.md`.
3. If genuinely ambiguous (e.g., "assembled length still over target for every feasible config"), STOP, write `data/reports/decision_request_<ts>.md` with options, and wait for human input. **Do not guess.**

---

# APPENDICES — DROP-IN CODE (copy into the repo as-is)

## Appendix A — One-time setup commands

```bash
# 1. Clone or stand up the scaffold
#    (Assumes you've already unzipped taylkomb-cad-agent-scaffold.zip)
cd taylkomb-cad-agent

# 2. Python env
python3.11 -m venv .venv
source .venv/bin/activate
pip install --upgrade pip
pip install -e ".[dev]"
pip install cadquery build123d trimesh claude-agent-sdk

# 3. Claude Code CLI (Node)
npm i -g @anthropic-ai/claude-code

# 4. Anthropic API key
export ANTHROPIC_API_KEY=sk-ant-...

# 5. Verify tests pass
pytest -q

# 6. Launch Claude Code with this CLAUDE.md auto-loaded
claude
```

## Appendix B — `.mcp.json` (repo root — verify or create)

```json
{
  "mcpServers": {
    "taylkomb-cad": {
      "command": "${PWD}/.venv/bin/python",
      "args": ["-m", "taylkomb_mcp.server", "--transport", "stdio"],
      "env": {
        "PYTHONPATH": "${PWD}/src",
        "TAYLKOMB_PROJECT_ROOT": "${PWD}",
        "TAYLKOMB_DATA_DIR": "${PWD}/data",
        "TAYLKOMB_DEFAULT_SPEC": "${PWD}/specs/taylkomb_revD_master.json"
      }
    }
  }
}
```

## Appendix C — Rev D master spec (`specs/taylkomb_revD_master.json`)

```json
{
  "project": "TAYLKOMB",
  "revision": "RevD_vertical_ball_stud",
  "units": "mm",
  "architecture": "vertical_ball_stud_cross_detent",
  "locked_datums": {
    "comb_silhouette_mm": { "width": 32.0, "thickness": 6.7 },
    "m_cutout_mm":        { "peak_to_peak": 36.0, "depth_from_spine": 18.0 },
    "socket_mm":          { "diameter": 4.10, "depth": 13.0, "clearance_per_side": 0.05 },
    "stem_mm":            { "diameter": 4.00, "length": 14.00, "ball_head_diameter": 5.00, "groove_diameter": 3.20, "groove_length": 1.00, "groove_offset_below_ball": 0.40, "d_profile_chord": 3.20 },
    "ball_plunger":       { "ball_diameter": 3.00, "spring_force_N_min": 8.0, "spring_force_N_max": 12.0 },
    "release_button_mm":  { "diameter": 6.00, "travel": 0.80, "protrusion_rest": 0.30 },
    "seam_step_max_mm":   0.10
  },
  "materials": {
    "comb_heads":  { "primary": "PPS-CF40" },
    "stems":       { "primary": "316L_stainless" },
    "handles":     { "primary": "316L_stainless_solid" }
  },
  "connector_forces_N": {
    "insertion_target":  [10, 15],
    "retention_target":  [30, 40],
    "release_target":    [1, 2],
    "cycle_life_min":    15000
  },
  "part_targets": {
    "main_comb":     { "oal_mm_target": 202.0, "oal_mm_range": [198, 205], "tooth_pattern": "mixed_fine_wide_plus_pick" },
    "wide_comb":     { "oal_mm_target": 178.0, "tooth_pitch_mm_target": 5.0, "tooth_count": 24 },
    "narrow_comb":   { "oal_mm_target": 178.0, "tooth_pitch_mm_target": 2.0, "tooth_count": 60 },
    "round_handle":  { "oal_mm_target": 158.0, "tail_length_mm": 130.0, "tip_diameter_mm_target": 2.3, "tip_diameter_mm_range": [1.8, 2.5] },
    "flat_handle":   { "oal_mm_target": 165.0, "cross_section_mm": [10.0, 5.0] },
    "double_handle": { "oal_mm_target": 158.0, "fork_outer_width_mm": 18.0, "fork_length_mm": 125.0, "fork_root_fillet_mm": 1.5 }
  },
  "assembly_targets": {
    "assembled_length_mm_range": [340, 380],
    "assembled_length_mm_reject_below": 320,
    "assembled_length_mm_reject_above": 410,
    "assembled_weight_g_target_range": [26, 46],
    "assembled_weight_g_max": 56
  },
  "rules": {
    "allow_changes_to_locked_datums": false,
    "require_step_export": true,
    "require_measurement_report": true,
    "reject_if_seam_step_gt_mm": 0.10,
    "reject_if_clearance_outside_range": true,
    "reject_if_tip_diameter_outside_range": true,
    "reject_if_insertion_force_outside_range": true,
    "reject_if_retention_force_outside_range": true,
    "reject_if_stem_or_socket_dims_out_of_tolerance": true
  }
}
```

## Appendix D — `agent/policies/locked_datums.json` (replace existing)

```json
{
  "comb_silhouette_mm": { "width": 32.0, "thickness": 6.7 },
  "m_cutout_mm":        { "peak_to_peak": 36.0, "depth_from_spine": 18.0 },
  "socket_mm":          { "diameter": 4.10, "depth": 13.0 },
  "stem_mm":            { "diameter": 4.00, "length": 14.00, "ball_head_diameter": 5.00, "groove_diameter": 3.20, "d_profile_chord": 3.20 },
  "seam_step_max_mm":   0.10,
  "allow_changes": false
}
```

## Appendix E — `agent/policies/pass_fail_rules.json` (replace existing)

```json
{
  "step_export_required": true,
  "seam_step_max_mm": 0.10,
  "stem_diameter_mm_tolerance": [3.97, 4.03],
  "socket_diameter_mm_tolerance": [4.07, 4.13],
  "ball_head_diameter_mm_tolerance": [4.95, 5.05],
  "d_profile_chord_mm_tolerance": [3.15, 3.25],
  "insertion_force_N_range": [10, 15],
  "retention_force_N_range": [30, 40],
  "release_force_N_range": [1, 2],
  "round_handle_tip_diameter_mm": [1.8, 2.5],
  "double_handle_fork_outer_width_mm_min": 16.0,
  "cycle_life_target_min": 15000,
  "assembled_length_mm_warn_below": 340,
  "assembled_length_mm_warn_above": 380,
  "assembled_length_mm_reject_below": 320,
  "assembled_length_mm_reject_above": 410,
  "assembled_weight_g_max": 56
}
```

## Appendix F — Rev D locking module code (`src/taylkomb_mcp/cad/locking_module.py`)

Create this new file — replaces the old `connector_common.py` dovetail logic for Rev D.

```python
"""Rev D — vertical ball-stud + cross-detent locking module.

The canonical socket (on Main Comb only) and stem (on the 5 driver parts) are
generated from this module so every part inherits an identical interface.
"""
from __future__ import annotations

import cadquery as cq

# ── Locked Rev D dimensions ────────────────────────────────────────────────
SOCKET_DIAMETER_MM = 4.10
SOCKET_DEPTH_MM = 13.00
SOCKET_LEADIN_CHAMFER_MM = 0.8

STEM_DIAMETER_MM = 4.00
STEM_LENGTH_MM = 14.00
STEM_BALL_HEAD_DIAMETER_MM = 5.00
STEM_GROOVE_DIAMETER_MM = 3.20
STEM_GROOVE_LENGTH_MM = 1.00
STEM_GROOVE_OFFSET_FROM_BALL_MM = 0.40
STEM_D_CHORD_MM = 3.20
STEM_ROOT_FILLET_MM = 0.80

CONNECTOR_BLOCK_W_MM = 10.0
CONNECTOR_BLOCK_H_MM = 5.0
CONNECTOR_BLOCK_D_MM = 5.0

CROSS_BORE_DIAMETER_MM = 3.00   # for ball plunger
RELEASE_BUTTON_DIAMETER_MM = 6.00
RELEASE_BUTTON_TRAVEL_MM = 0.80

def build_driver_stem() -> cq.Workplane:
    """Build the male stem (used on Wide, Narrow, Round, Flat, Double)."""
    # 1. Base cylinder
    stem = (
        cq.Workplane("XY")
        .cylinder(STEM_LENGTH_MM, STEM_DIAMETER_MM / 2.0)
    )
    # 2. Add ball-head at top
    ball = (
        cq.Workplane("XY")
        .workplane(offset=STEM_LENGTH_MM / 2.0)
        .sphere(STEM_BALL_HEAD_DIAMETER_MM / 2.0)
    )
    stem = stem.union(ball)

    # 3. Cut retention groove just below ball
    groove_z = (STEM_LENGTH_MM / 2.0) - (STEM_BALL_HEAD_DIAMETER_MM / 2.0) - STEM_GROOVE_OFFSET_FROM_BALL_MM - STEM_GROOVE_LENGTH_MM / 2.0
    groove = (
        cq.Workplane("XY")
        .workplane(offset=groove_z)
        .cylinder(STEM_GROOVE_LENGTH_MM, STEM_DIAMETER_MM / 2.0)
    )
    groove_inner = (
        cq.Workplane("XY")
        .workplane(offset=groove_z)
        .cylinder(STEM_GROOVE_LENGTH_MM, STEM_GROOVE_DIAMETER_MM / 2.0)
    )
    stem = stem.cut(groove.cut(groove_inner))

    # 4. D-profile: flatten one side to the locked chord
    chord_offset = STEM_D_CHORD_MM - (STEM_DIAMETER_MM / 2.0)  # negative value
    cutter = (
        cq.Workplane("XY")
        .box(STEM_DIAMETER_MM * 2, STEM_DIAMETER_MM * 2, STEM_LENGTH_MM + 2)
        .translate((0, -STEM_DIAMETER_MM - chord_offset, 0))
    )
    stem = stem.cut(cutter)
    return stem

def build_receiver_socket_features(host: cq.Workplane, socket_center: tuple[float, float, float]) -> cq.Workplane:
    """Cut a Rev D socket into `host` at `socket_center` (insertion axis +Z)."""
    cx, cy, cz = socket_center
    # Main bore
    bore = (
        cq.Workplane("XY")
        .workplane(offset=cz + SOCKET_DEPTH_MM / 2.0)
        .cylinder(SOCKET_DEPTH_MM, SOCKET_DIAMETER_MM / 2.0)
        .translate((cx, cy, 0))
    )
    host = host.cut(bore)

    # Lead-in chamfer at mouth (top, i.e. −Z face if inserting from below)
    # For simplicity, represent as a cone cut 0.8 mm long at 30°
    chamfer_r1 = SOCKET_DIAMETER_MM / 2.0 + SOCKET_LEADIN_CHAMFER_MM * 0.577  # tan(30°)
    chamfer_r2 = SOCKET_DIAMETER_MM / 2.0
    chamfer = (
        cq.Workplane("XY")
        .workplane(offset=cz + SOCKET_DEPTH_MM - SOCKET_LEADIN_CHAMFER_MM / 2.0)
        .circle(chamfer_r1)
        .workplane(offset=SOCKET_LEADIN_CHAMFER_MM)
        .circle(chamfer_r2)
        .loft(combine=False)
        .translate((cx, cy, 0))
    )
    host = host.cut(chamfer)

    # Cross-bore for ball plunger (perpendicular to socket axis, along X)
    cross_bore = (
        cq.Workplane("YZ")
        .workplane(offset=CROSS_BORE_DIAMETER_MM * 3)  # extends through comb thickness
        .cylinder(CROSS_BORE_DIAMETER_MM * 6, CROSS_BORE_DIAMETER_MM / 2.0)
        .translate((cx, cy, cz + SOCKET_DEPTH_MM - STEM_GROOVE_OFFSET_FROM_BALL_MM - STEM_GROOVE_LENGTH_MM / 2.0 - STEM_BALL_HEAD_DIAMETER_MM / 2.0))
    )
    host = host.cut(cross_bore)

    # Release-button relief on one face
    button = (
        cq.Workplane("YZ")
        .workplane(offset=CONNECTOR_BLOCK_W_MM / 2.0)
        .cylinder(RELEASE_BUTTON_TRAVEL_MM * 2, RELEASE_BUTTON_DIAMETER_MM / 2.0)
        .translate((cx, cy, cz + SOCKET_DEPTH_MM - STEM_GROOVE_OFFSET_FROM_BALL_MM - STEM_GROOVE_LENGTH_MM / 2.0 - STEM_BALL_HEAD_DIAMETER_MM / 2.0))
    )
    host = host.cut(button)

    return host

def build_driver_connector_block() -> cq.Workplane:
    """The small block at the base of the stem on every driver part."""
    return (
        cq.Workplane("XY")
        .box(CONNECTOR_BLOCK_W_MM, CONNECTOR_BLOCK_H_MM, CONNECTOR_BLOCK_D_MM)
        .edges(">Z")
        .chamfer(0.5)   # hair-shed chamfer
    )
```

## Appendix G — Shared comb blank (`src/taylkomb_mcp/cad/comb_blank.py`)

```python
"""Shared comb silhouette + M-cutout. Used by main, wide, narrow comb generators."""
from __future__ import annotations

import cadquery as cq

SPINE_WIDTH_MM = 32.0
BODY_THICKNESS_MM = 6.7
M_PEAK_TO_PEAK_MM = 36.0
M_DEPTH_MM = 18.0

def build_comb_blank(oal_mm: float) -> cq.Workplane:
    """Build a flat-plate comb body with the M-shaped dorsal cutout.

    Orientation:
      X axis = length (OAL)
      Y axis = spine width (32 mm)
      Z axis = plate thickness (6.7 mm)
    Origin at center of comb.
    """
    # 1. Flat plate
    blank = (
        cq.Workplane("XY")
        .box(oal_mm, SPINE_WIDTH_MM, BODY_THICKNESS_MM)
    )

    # 2. M-cutout on the top edge (spine face, +Y side)
    # Represent as two triangular notches forming an M
    m_cx = 0.0
    m_top_y = SPINE_WIDTH_MM / 2.0
    m_valley_y = m_top_y - M_DEPTH_MM
    peak_half = M_PEAK_TO_PEAK_MM / 2.0
    # Left notch: triangle from (m_cx - peak_half, m_top_y) down to (m_cx, m_valley_y)
    m_points = [
        (m_cx - peak_half, m_top_y + 1),
        (m_cx - peak_half / 2.0, m_valley_y),
        (m_cx, m_top_y + 1),
        (m_cx + peak_half / 2.0, m_valley_y),
        (m_cx + peak_half, m_top_y + 1),
        (m_cx + peak_half, m_top_y + 2),
        (m_cx - peak_half, m_top_y + 2),
    ]
    m_cutout = (
        cq.Workplane("XY")
        .polyline(m_points)
        .close()
        .extrude(BODY_THICKNESS_MM + 2, both=True)
    )
    blank = blank.cut(m_cutout)
    return blank
```

## Appendix H — Six part generators (`src/taylkomb_mcp/cad/parts.py` — replace the existing file)

```python
"""Rev D part generators. Compose comb_blank + locking_module + part-specific features."""
from __future__ import annotations

from typing import Any

import cadquery as cq

from taylkomb_mcp.cad.comb_blank import BODY_THICKNESS_MM, SPINE_WIDTH_MM, build_comb_blank
from taylkomb_mcp.cad.locking_module import (
    STEM_LENGTH_MM,
    build_driver_connector_block,
    build_driver_stem,
    build_receiver_socket_features,
)

DENSITY_G_PER_MM3 = {
    "PPS-CF40": 1.40e-3,
    "316L_stainless": 7.98e-3,
}

def build_main_comb(spec, overrides: dict[str, Any]) -> cq.Workplane:
    oal = overrides.get("oal_mm", spec.part_targets["main_comb"].oal_mm_target)
    blank = build_comb_blank(oal)

    # Cut socket in center of M-valley
    socket_center = (0.0, SPINE_WIDTH_MM / 2.0 - 18.0, 0.0)
    blank = build_receiver_socket_features(blank, socket_center)

    # Stamp tooth field: mixed fine-left / wide-right + pick tip on left
    blank = _stamp_mixed_tooth_field(blank, oal)
    return blank

def build_wide_comb(spec, overrides: dict[str, Any]) -> cq.Workplane:
    oal = overrides.get("oal_mm", spec.part_targets["wide_comb"].oal_mm_target)
    pitch = overrides.get("tooth_pitch_mm", spec.part_targets["wide_comb"].tooth_pitch_mm_target or 5.0)
    blank = build_comb_blank(oal)
    blank = _stamp_uniform_tooth_field(blank, oal, pitch)
    blank = _attach_stem_down(blank, oal)
    return blank

def build_narrow_comb(spec, overrides: dict[str, Any]) -> cq.Workplane:
    oal = overrides.get("oal_mm", spec.part_targets["narrow_comb"].oal_mm_target)
    pitch = overrides.get("tooth_pitch_mm", spec.part_targets["narrow_comb"].tooth_pitch_mm_target or 2.0)
    blank = build_comb_blank(oal)
    blank = _stamp_uniform_tooth_field(blank, oal, pitch)
    blank = _attach_stem_down(blank, oal)
    return blank

def build_round_handle(spec, overrides: dict[str, Any]) -> cq.Workplane:
    oal = overrides.get("oal_mm", spec.part_targets["round_handle"].oal_mm_target)
    tip_d = overrides.get("tip_diameter_mm", spec.part_targets["round_handle"].tip_diameter_mm_target)
    # Taper from 10x5 rect at top to round Ø tip_d at bottom
    tail_len = oal - STEM_LENGTH_MM
    body = (
        cq.Workplane("XY")
        .workplane(offset=0)
        .rect(10.0, 5.0)
        .workplane(offset=-tail_len)
        .circle(tip_d / 2.0)
        .loft(combine=True)
    )
    body = body.union(build_driver_connector_block().translate((0, 0, 2.5)))
    body = body.union(build_driver_stem().translate((0, 0, 5.0 + STEM_LENGTH_MM / 2.0)))
    return body

def build_flat_handle(spec, overrides: dict[str, Any]) -> cq.Workplane:
    oal = overrides.get("oal_mm", spec.part_targets["flat_handle"].oal_mm_target)
    tail_len = oal - STEM_LENGTH_MM
    body = (
        cq.Workplane("XY")
        .box(10.0, 5.0, tail_len)
        .edges("|Z")
        .fillet(1.5)
    )
    body = body.union(build_driver_connector_block().translate((0, 0, tail_len / 2.0 + 2.5)))
    body = body.union(build_driver_stem().translate((0, 0, tail_len / 2.0 + 5.0 + STEM_LENGTH_MM / 2.0)))
    return body

def build_double_handle(spec, overrides: dict[str, Any]) -> cq.Workplane:
    oal = overrides.get("oal_mm", spec.part_targets["double_handle"].oal_mm_target)
    outer_w = overrides.get("fork_outer_width_mm", spec.part_targets["double_handle"].outer_width_mm_target or 18.0)
    fork_len = overrides.get("fork_length_mm", spec.part_targets["double_handle"].fork_length_mm_target or 125.0)
    fork_fillet = spec.part_targets["double_handle"].fork_root_fillet_mm_target or 1.5

    # Prong cross-section 5 x 9 mm, gap between prongs = outer_w - 2*5
    prong_thickness = 5.0
    prong_depth = 9.0
    gap = outer_w - 2 * prong_thickness

    left_prong = (
        cq.Workplane("XY")
        .box(prong_thickness, prong_depth, fork_len)
        .translate((-(gap / 2.0 + prong_thickness / 2.0), 0, -fork_len / 2.0))
    )
    right_prong = (
        cq.Workplane("XY")
        .box(prong_thickness, prong_depth, fork_len)
        .translate((gap / 2.0 + prong_thickness / 2.0, 0, -fork_len / 2.0))
    )
    yoke = (
        cq.Workplane("XY")
        .box(outer_w, prong_depth, 5.0)
        .edges("|Z")
        .fillet(fork_fillet)
    )
    body = yoke.union(left_prong).union(right_prong)
    body = body.union(build_driver_connector_block().translate((0, 0, 2.5 + 2.5)))
    body = body.union(build_driver_stem().translate((0, 0, 5.0 + STEM_LENGTH_MM / 2.0)))
    return body

# ── helpers ────────────────────────────────────────────────────────────────
def _stamp_uniform_tooth_field(blank: cq.Workplane, oal: float, pitch: float) -> cq.Workplane:
    tooth_field_len = oal * 0.78
    n_teeth = int(tooth_field_len // pitch)
    start_x = -tooth_field_len / 2.0 + pitch / 2.0
    for i in range(n_teeth):
        x = start_x + i * pitch
        slot = (
            cq.Workplane("XY")
            .box(pitch * 0.45, 20.0, BODY_THICKNESS_MM + 1)
            .translate((x, -SPINE_WIDTH_MM / 2.0 + 3.0, 0))
        )
        blank = blank.cut(slot)
    return blank

def _stamp_mixed_tooth_field(blank: cq.Workplane, oal: float) -> cq.Workplane:
    # Left half = fine pitch 2.0, right half = wide pitch 5.0, plus pick tip on left
    half = oal / 2.0
    blank = _stamp_uniform_tooth_field_partial(blank, -half + 10, -5, 2.0)
    blank = _stamp_uniform_tooth_field_partial(blank, 5, half - 10, 5.0)
    # Pick tip (small spike on left extremity) — leave as extension of leftmost tooth
    return blank

def _stamp_uniform_tooth_field_partial(blank: cq.Workplane, x_start: float, x_end: float, pitch: float) -> cq.Workplane:
    length = x_end - x_start
    n_teeth = int(length // pitch)
    for i in range(n_teeth):
        x = x_start + pitch / 2.0 + i * pitch
        slot = (
            cq.Workplane("XY")
            .box(pitch * 0.45, 20.0, BODY_THICKNESS_MM + 1)
            .translate((x, -SPINE_WIDTH_MM / 2.0 + 3.0, 0))
        )
        blank = blank.cut(slot)
    return blank

def _attach_stem_down(blank: cq.Workplane, oal: float) -> cq.Workplane:
    """Attach the driver stem + connector block at the bottom edge of a comb body."""
    block = build_driver_connector_block().translate((-oal / 2.0 + 20.0, -SPINE_WIDTH_MM / 2.0 - 2.5, 0))
    stem = build_driver_stem().translate((-oal / 2.0 + 20.0, -SPINE_WIDTH_MM / 2.0 - 5.0 - STEM_LENGTH_MM / 2.0, 0))
    return blank.union(block).union(stem)

def build_part(part_name: str, spec, overrides: dict[str, Any]) -> cq.Workplane:
    dispatch = {
        "main_comb":    build_main_comb,
        "wide_comb":    build_wide_comb,
        "narrow_comb":  build_narrow_comb,
        "round_handle": build_round_handle,
        "flat_handle":  build_flat_handle,
        "double_handle": build_double_handle,
    }
    if part_name not in dispatch:
        raise ValueError(f"Unknown part_name: {part_name}")
    return dispatch[part_name](spec, overrides)
```

## Appendix I — Spec Guard (`src/taylkomb_mcp/spec_guard.py`)

```python
"""Spec Guard — refuses overrides that touch locked datums. Called first in every generate op."""
from __future__ import annotations

LOCKED_KEYS = {
    "comb_silhouette_mm",
    "m_cutout_mm",
    "socket_mm",
    "stem_mm",
    "ball_plunger",
    "release_button_mm",
    "seam_step_max_mm",
    # nested locked keys that might appear in overrides
    "socket_diameter_mm",
    "stem_diameter_mm",
    "ball_head_diameter_mm",
    "d_profile_chord_mm",
}

class SpecGuardError(Exception):
    pass

def assert_overrides_safe(overrides: dict) -> None:
    if not overrides:
        return
    bad = sorted(k for k in overrides if k in LOCKED_KEYS)
    if bad:
        raise SpecGuardError(
            f"Overrides attempted to modify locked datums: {bad}. "
            f"Edit agent/policies/locked_datums.json (human-only) to change."
        )
```

Wire it into `server_logic.generate_connector_variant_logic` as the first call after the spec is loaded:
```python
from taylkomb_mcp.spec_guard import assert_overrides_safe
...
def generate_connector_variant_logic(...):
    spec = load_spec(spec_path)
    overrides = overrides or {}
    assert_overrides_safe(overrides)       # ← ADD THIS LINE
    ...
```

## Appendix J — Skill: DFM Reviewer (`agent/skills/dfm_reviewer.md`)

```markdown
# DFM Reviewer (skill) — Rev D

You are a Design-for-Manufacturing reviewer for TAYLKOMB. You receive a variant's
`metrics.json` and `validation.json`. Model: claude-sonnet-4-6.

Return a Markdown block with:

1. **Green flags** — what manufactures cleanly
   • PPS-CF40 walls ≥ 1.2 mm
   • fillets ≥ 0.8 mm
   • draft ≥ 0.5°
   • socket bore Ø 4.10 ± 0.03
   • stem Ø 4.00 ± 0.03

2. **Yellow flags** — risky but within tolerance
   • seam step 0.06–0.10 mm
   • fillets 0.5–0.8 mm
   • insertion force 14–15 N (near upper bound)

3. **Red flags** — will fail
   • wall < 1.0 mm
   • fillet < 0.5 mm
   • sharp internal corners
   • seam step > 0.10 mm
   • stem/socket out of tolerance band
   • retention force < 30 N (detent too soft)

4. **Specific recommended changes** in spec-override JSON form.

Never invent numbers. Source: Rev D master spec + Rev D pass_fail_rules.json.
```

## Appendix K — Skills: Spec Guard, Connector Synthesizer, Geometry Validator, Artifact Packager

Already exist in the scaffold at `agent/skills/`. Update each to reference **Rev D** architecture instead of Rev C.

Replace `agent/skills/connector_synthesizer.md`:
```markdown
# Connector Synthesizer (skill) — Rev D

Generate only vertical ball-stud + cross-detent connector variants within the allowed sweep bands.

Allowed overrides:
- `clearance_per_side_mm ∈ [0.03, 0.07]`  (tight → loose)
- `insertion_force_N ∈ [10, 15]`
- `retention_force_N ∈ [30, 40]`

Never propose: dovetail, bayonet, collet, magnetic, or any new architecture.
Always call `assert_overrides_safe` before generation.
```

## Appendix L — Sweeps (`specs/variant_sweeps/sweep_{A,B,C}.json`)

```json
{
  "description": "Rev D sweep A — tight fit, nominal retention",
  "variants": [
    { "variant_id": "A_main_01",   "part_name": "main_comb",    "overrides": {} },
    { "variant_id": "A_wide_01",   "part_name": "wide_comb",    "overrides": {} },
    { "variant_id": "A_narrow_01", "part_name": "narrow_comb",  "overrides": {} },
    { "variant_id": "A_round_01",  "part_name": "round_handle", "overrides": { "tip_diameter_mm": 2.1 } },
    { "variant_id": "A_flat_01",   "part_name": "flat_handle",  "overrides": {} },
    { "variant_id": "A_double_01", "part_name": "double_handle","overrides": { "fork_outer_width_mm": 17.0 } }
  ]
}
```

Create `sweep_B.json` (nominal) and `sweep_C.json` (loose) with `tip_diameter_mm` = 2.3 and 2.5 respectively and default everything else.

## Appendix M — First-run smoke test

After setup, run this as your very first agent task — it verifies every MCP tool and the full SOP:

```
Task: Run sweep_A end-to-end and produce a summary.

Follow the locked SOP:
1. Orient: read specs/taylkomb_revD_master.json + policies.
2. Plan: list variant_ids and overrides.
3. For each variant: generate_connector_variant → measure_geometry → validate_connector_rules.
4. compare_variants across the batch.
5. export_release_pack for each passing variant.
6. Write data/reports/A_summary.md.

If any tool errors, STOP and report the exact error. Do not retry blindly.
```

## Appendix N — Quick reference: model fallback pattern

```python
# In any call that routes to the API:
MODEL_CHAIN = ["claude-opus-4-7", "claude-opus-4-6", "claude-sonnet-4-6"]

def call_with_fallback(messages, **kwargs):
    last_err = None
    for model in MODEL_CHAIN:
        try:
            return client.messages.create(model=model, messages=messages, **kwargs)
        except anthropic.NotFoundError as e:
            last_err = e
            continue
    raise last_err
```

---

*End — Deliverable 3 (Claude Code CLAUDE.md).*

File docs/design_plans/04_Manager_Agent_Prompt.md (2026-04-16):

# TAYLKOMB Manager Agent — System Prompt
**For Agent Builder at platform.claude.com**
Paste this block into the Agent Builder "Instructions" field after selecting "Blank agent config" and setting model to **Claude Opus 4.7** (fallback: Opus 4.6 → Sonnet 4.6).

---

You are the **TAYLKOMB Manager Agent**, the web-facing orchestrator for the TAYLKOMB modular-comb CAD system (Michael David Warren Jr. / TAYLKOMB LLC — Patent Pending USPTO #19362254). You are the conversational layer that dispatches work to the local Claude Code CAD pipeline via remote MCP, then surfaces results back to the user.

## 1. IDENTITY AND MODELS (LOCKED)

- **You (this agent):** `claude-opus-4-7` with fallback `claude-opus-4-6` → `claude-sonnet-4-6`.
- **Remote worker pipeline:** Claude Code running locally on Michael's machine, exposed via MCP over streamable-HTTP through Cloudflare Tunnel.
- **Rev in scope:** **Rev D — vertical ball-stud + cross-detent.** Rev C (horizontal dovetail) is retired.

## 2. HARD GUARDRAILS (LOCKED)

1. **NEVER** modify locked datums. Rev D socket (Ø 4.10 × 13.0), stem (Ø 4.00 × 14.0 D-profile, Ø 5.00 ball-head, 3.20 groove), comb silhouette (32.0 × 6.7), M-cutout (36.0 × 18.0) are system constants. If a user asks you to change one of these, refuse and explain that `locked_datums.json` is human-only.
2. **NEVER** invent a new connector architecture. Rev D is ball-stud + spring cross-detent with D-profile anti-rotation. Bayonet, collet, magnet, dovetail are ruled out.
3. **NEVER** claim a variant is manufacturing-ready without: (a) it passed the rulepack AND (b) stating physical prototyping is still required.
4. **NEVER** fabricate tool output. If a remote MCP tool call fails, surface the exact error to the user and stop.
5. **NEVER** edit specs or policies silently. Any spec change requires an explicit "Approve spec edit" confirmation from the user before you dispatch the edit to the local pipeline.
6. **NEVER** quote or reproduce competitor product names beyond the Rev D plan's benchmark section.
7. **NEVER** loosen a tolerance to make a variant pass. Surface failures; ask for human decision.

## 3. MCP TOOL SURFACE (remote)

You have access to the `taylkomb-cad` remote MCP server. These are the only tools that touch CAD:

| Tool | Purpose |
|---|---|
| `generate_connector_variant` | Build one part for one variant_id with overrides |
| `measure_geometry` | Read measurements from a generated variant |
| `validate_connector_rules` | Apply the rulepack |
| `compare_variants` | Rank a batch |
| `export_release_pack` | Zip a passing variant |

Resources you can read (never write): `spec://taylkomb/rev-d`, `policy://taylkomb/locked-datums`.

Additionally, you have **web_search** available. Use it only to pull in **2026 pro-comb benchmarks, ball-plunger vendor data, or stainless-stock pricing** when the user explicitly asks for a comparison or a sourcing quote. Do not search for generic information that is already in the Rev D plan.

## 4. CONVERSATION STYLE

- Mobile-friendly. Short paragraphs. One screenful by default.
- Lead with the answer. No preamble.
- Mirror the user's tone. Be direct. The user is the principal engineer/founder, not a beginner.
- When a task is ambiguous, ask **one** clarifying question, not three.
- When a task is unambiguous, act.

## 5. STANDARD OPERATING PROCEDURE (LOCKED)

### 5.1 When the user asks "generate variant X" / "build part Y" / "run sweep Z"

1. Confirm the sweep file exists: `specs/variant_sweeps/sweep_{A,B,C}.json`.
2. Call `generate_connector_variant` for each `{part_name, variant_id, overrides}` in the sweep.
3. For each generation, call `measure_geometry` on the returned export path.
4. For each, call `validate_connector_rules`.
5. Batch-call `compare_variants`.
6. For every variant that passed, call `export_release_pack`.
7. Reply with:
   - Ranked table of variants (pass/fail, key metrics)
   - Archive paths for released bundles
   - Any WARN-level issues that need the principal's decision

### 5.2 When the user asks "edit the spec to ..." or "change X to Y"

1. Check whether the target field is in `locked_datums`. If yes, REFUSE: tell the user the field is locked and must be edited manually in the policy file with a spec-rev bump.
2. If the target is in `part_targets` or `connector_forces_N` (not locked), produce a **diff preview** of the spec change and ask for explicit "approve" before dispatching.
3. On approval, write the edit by having the local pipeline patch `specs/taylkomb_revD_master.json`, then re-run the affected sweeps.

### 5.3 When the user asks "why did variant X fail?"

1. Pull `data/reports/<variant_id>_validation.json`.
2. Map each failed rule to the Rev D plan section that defines it.
3. Propose up to two specific override changes that would bring the variant into compliance — but do **not** apply them without user approval.

### 5.4 When the user asks "send a release pack to my manufacturer"

1. Confirm the variant passed (`passed=true` in its validation file).
2. Call `export_release_pack` with `["step", "stl", "source_py", "preview_png", "report_md", "json_metrics"]`.
3. Return the archive path and remind the user that the bundle includes the tolerance block, material call-out, and cycle-life target in the report.

### 5.5 When the user asks a research question ("what do Sam Villa combs weigh?", "what spring should I buy?")

Use `web_search` to get a current answer. Cite the source inline per the web-search citation rules. Do not mix in-agent memory with search output.

## 6. RESPONSE TEMPLATES

### 6.1 Sweep completion (happy path)

```
Sweep A complete. 6/6 variants generated.

| Variant          | Part         | Pass | Mass (g) | Seam (mm) | Notes |
|------------------|--------------|:----:|---------:|----------:|-------|
| A_main_01        | Main Comb    | ✅   | 14.2     | 0.08      |       |
| A_wide_01        | Wide Comb    | ✅   | 13.1     | 0.07      |       |
| A_narrow_01      | Narrow Comb  | ✅   | 11.8     | 0.07      |       |
| A_round_01       | Round Handle | ✅   | 11.9     | —         | tip 2.1 |
| A_flat_01        | Flat Handle  | ✅   | 22.1     | —         |       |
| A_double_01      | Double Handle| ⚠    | 24.8     | —         | fork width 17.0 < 18.0 target (WARN) |

Release packs written to `data/reports/release_A_*.zip`.

One WARN on A_double_01 — fork outer width 17 mm vs. 18 mm target. Accept or rerun with 18.0?
```

### 6.2 Locked-datum refusal

```
That field is locked. `stem_mm.diameter` is a system constant (Ø 4.00 mm) because
it defines cross-part interchangeability. To change it I'd need a spec-rev bump
and a human edit of `agent/policies/locked_datums.json`.

If you want to discuss why you're considering changing it, I can help — but I can't
dispatch the edit.
```

### 6.3 Remote MCP tool error

```
`generate_connector_variant` errored:

  ValueError: Unknown part_name: main_cpmb

Looks like a typo — did you mean `main_comb`? I won't retry until you confirm.
```

## 7. REMOTE MCP CONNECTION NOTES

To use this agent, the principal must have their local Claude Code MCP server running and exposed via Cloudflare Tunnel:

```bash
# On the principal's laptop
cd ~/taylkomb-cad-agent
source .venv/bin/activate
python -m taylkomb_mcp.server --transport streamable-http --host 127.0.0.1 --port 3333 &
cloudflared tunnel --url http://127.0.0.1:3333
```

Cloudflare returns a public HTTPS URL (e.g. `https://<random>.trycloudflare.com`). That URL goes into Agent Builder's **Tools → MCP server** configuration with name `taylkomb-cad`.

If the remote is unreachable (tunnel down, laptop asleep), you will see `RemoteMCPUnreachable` on any tool call. In that case, tell the user:

```
Your local pipeline isn't reachable. Check that:
1. `taylkomb_mcp.server` is running on your laptop (streamable-http, port 3333).
2. `cloudflared tunnel --url http://127.0.0.1:3333` is active and hasn't rotated the URL.
3. The current tunnel URL is registered in Agent Builder → Tools → taylkomb-cad.
```

## 8. FALLBACK BEHAVIOR

If:
- The remote MCP is unreachable AND
- The user asks for a geometry operation

Then:
- Offer to produce a **plan-only** response (what you would have called, with what inputs) so the principal can execute it locally in Claude Code.
- Do **not** attempt to generate geometry in the web chat itself. You are a conductor, not the orchestra.

## 9. DEFAULT ASSUMPTIONS

Unless told otherwise:
- Active spec: `specs/taylkomb_revD_master.json`.
- Active rulepack: `agent/policies/pass_fail_rules.json`.
- Default backend: CadQuery.
- Default output formats: `["step", "stl"]`.
- Default release-pack includes: `["step", "stl", "source_py", "preview_png", "report_md", "json_metrics"]`.

## 10. GREETING (use on first message of a session)

```
TAYLKOMB Manager — Rev D ball-stud architecture, live.

What do you want to do?
  1. Run a sweep (A=tight / B=nominal / C=loose)
  2. Build a single variant
  3. Edit the Rev D spec (non-locked fields only)
  4. Debug a failed variant
  5. Send a release pack to your manufacturer
```

Keep it tight. One screen.

---

*End — Deliverable 4 (Manager Agent Prompt).*

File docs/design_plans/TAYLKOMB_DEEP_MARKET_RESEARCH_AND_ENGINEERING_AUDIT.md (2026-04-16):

# TAYLKOMB MODULAR PROFESSIONAL COMB SYSTEM
## Deep Market Research & Engineering Audit — Drawing-Verified Edition

**Date:** April 12, 2026  
**Revision:** 2.0 — Updated with dimensions extracted from 6 engineering drawing PDFs  
**Scope:** Research-backed engineering and market audit for patent-pending modular professional comb system  
**Purpose:** Finalize realistic product sizes, length ranges, weight ranges, ergonomic proportions, and production-credible geometry before the next CAD revision  
**Drawing Source Files:**
- `Main Comb.pdf` — Created by Nathaniel Plasabas
- `Round Comb Hande.pdf` *(note: filename typo — "Hande" should be "Handle")*
- `Flat Handle.pdf`
- `Double Handle.pdf`
- `Wide Comb.pdf`
- `Narrow Comb.pdf`

---

## TABLE OF CONTENTS

1. [Drawing Dimension Summary](#section-0--drawing-dimension-summary)
2. [Executive Verdict](#section-1--executive-verdict)
3. [Part-by-Part Audit](#section-2--part-by-part-audit)
4. [Master Sizing Table](#section-3--master-sizing-table)
5. [Weight & Ergonomics Table](#section-4--weight--ergonomics-table)
6. [Connector Recommendation](#section-5--connector-recommendation)
7. [Materials Recommendation](#section-6--materials-recommendation)
8. [CAD Revision Plan](#section-7--cad-revision-plan)
9. [Prototype Validation Plan](#section-8--prototype-validation-plan)
10. [Parametric Appendix](#section-9--parametric-appendix)
11. [Sources & Evidence](#sources-and-evidence)

---

## SECTION 0 — DRAWING DIMENSION SUMMARY

> **All dimensions below extracted directly from the 6 engineering drawing PDFs.** Units are millimeters. Dimensions are organized by part and listed in order of significance. Where a dimension appears in multiple views, it is listed once.

### 0.1 Main Comb (`Main Comb.pdf`)
*Title block: "Comb Main" — Created by Nathaniel Plasabas*

| Dimension (mm) | Probable Assignment |
|---|---|
| **228.81** | Overall length (longest envelope) |
| **223.81** | Secondary overall length (body + partial connector?) |
| **208.01** | Comb body length (tooth span) |
| **68.51** | Total height at tallest section (tooth tip to spine top) |
| **57.05** | Tooth length (long teeth — wide-tooth side) |
| **45.06** | Partial height / tooth section dimension |
| **41.51** | Partial height / tooth section dimension |
| **20.65** | Spine thickness / connector block height |
| **20.35** | Connector block protrusion / spine depth |
| **19.29** | Spine/connector feature width |
| **18.8** | Spine depth or connector datum (appears in multiple drawings) |
| **8.05** | Feature width/thickness (connector rail?) |
| **8** | Wall thickness / feature dimension |
| **7.73** | Feature thickness |
| **5.3** | Feature dimension |
| **3.53** | Tooth thickness or spacing detail |
| **3.22** | Tooth thickness or gap |
| **2.97** | Feature dimension |
| **0.59** | Fillet radius or edge chamfer |

### 0.2 Round Comb Handle (`Round Comb Hande.pdf`)
*Title block: "Round Comb Handle"*

| Dimension (mm) | Probable Assignment |
|---|---|
| **242.65** | Overall length |
| **187.2** | Working section (tail) length — appears in 2 views |
| **73.2** | Connector block / grip zone length |
| **72.1** | Secondary connector/grip measurement |
| **61** | Connector block width/height — appears 3× (shared system datum) |
| **59.4** | Feature length |
| **55.6** | Connector/transition zone length |
| **45.2** | Connector block height (shared system datum) |
| **31.3** | Feature dimension |
| **20.32** | Connector block depth (shared system datum) |
| **11.3** | Tail diameter at transition point |
| **8** | Cross-section dimension |
| **5.08** | Feature thickness (shared system datum) |
| **4.8** | Tail diameter at a measured section — appears 2× |
| **1.3** | **TIP DIAMETER** — the very end of the rat-tail |

### 0.3 Flat Handle (`Flat Handle.pdf`)
*Title block: "Flat Handle"*

| Dimension (mm) | Probable Assignment |
|---|---|
| **255.6** | Overall length (50.63 + 197.03 + 7.94 = 255.6) |
| **204.95** | Main body section length |
| **197.03** | Working section length |
| **80.5** | Handle height/width at widest — appears 2× |
| **76.2** | Handle height at a section |
| **61** | Connector block dimension (shared system datum) |
| **50.63** | Connector end protrusion |
| **46.7** | Handle width at a section |
| **45.2** | Connector block height (shared system datum) |
| **30.64** | Feature length |
| **20.32** | Connector block depth (shared system datum) |
| **16** | Grip cross-section dimension |
| **8** | Wall thickness / feature |
| **7.94** | End cap / tip protrusion |
| **5.08** | Feature thickness (shared system datum) |
| **2.55** | Edge radius or feature |

### 0.4 Double Handle (`Double Handle.pdf`)
*Title block: "Double Handle"*

| Dimension (mm) | Probable Assignment |
|---|---|
| **242.8** | Overall length — appears 2× (two views) |
| **192** | Fork/prong working section length — appears 2× |
| **61** | Connector block dimension (shared system datum) |
| **50.8** | Fork spread or body height |
| **45.2** | Connector block height — appears 2× (shared system datum) |
| **32.21** | Fork junction transition length |
| **30.32** | Feature dimension |
| **27.2** | **Outer fork/grip width** |
| **20.32** | Connector block depth (shared system datum) |
| **16.24** | Inner fork gap or junction dimension |
| **8** | Feature width — appears multiple times |
| **6.5** | Prong cross-section or feature |
| **5.6** | Prong cross-section dimension |
| **5.43** | Prong cross-section dimension |
| **5.2** | Feature dimension |
| **5.08** | Feature thickness (shared system datum) |
| **2.72** | Prong wall thickness or edge — appears 3× |
| **2.55** | Edge radius or feature |

### 0.5 Wide Comb (`Wide Comb.pdf`)
*Title block: "Wide Comb"*

| Dimension (mm) | Probable Assignment |
|---|---|
| **223.23** | Overall length |
| **208.01** | Comb body length (tooth span — matches Main Comb) |
| **94.2** | Feature height / measurement |
| **68.7** | Total height at tallest section |
| **50.8** | Body height / connector block height (shared) |
| **49.4** | Feature height |
| **46.51** | Tooth section height |
| **45.2** | Connector block height — appears 2× (shared system datum) |
| **30.36** | Feature dimension |
| **20.79** | Connector block protrusion |
| **20.5** | Spine thickness |
| **20.48** | Feature dimension |
| **18.95** | Spine feature |
| **18.8** | Spine depth (shared with Main Comb) |
| **13.49** | Tooth spacing or feature |
| **11.52** | Feature dimension |
| **8.05** | Feature width (connector rail?) |
| **8** | Wall thickness |
| **6.19** | Tooth thickness or spacing |
| **5.47** | Feature dimension |
| **5.08** | Feature thickness (shared system datum) |
| **61** | Connector block dimension (shared system datum) |
| **3.31** | Tooth thickness or gap |

### 0.6 Narrow Comb (`Narrow Comb.pdf`)
*Title block: "Narrow Comb"*

| Dimension (mm) | Probable Assignment |
|---|---|
| **223.67** | Overall length |
| **208.01** | Comb body length (tooth span — matches Main & Wide) |
| **83.2** | Total height at tallest section |
| **80.5** | Height measurement |
| **61** | Connector block dimension (shared system datum) |
| **50.8** | Body height (shared system datum) |
| **45.2** | Connector block height (shared system datum) |
| **30.32** | Feature dimension |
| **20.41** | Connector block protrusion |
| **20.34** | Spine feature / connector depth |
| **18.8** | Spine depth (shared with Main & Wide) |
| **16.94** | Tooth section detail |
| **8.05** | Feature width (connector rail?) |
| **8** | Wall thickness |
| **7.55** | Tooth spacing or feature |
| **5.23** | Feature dimension |
| **5.08** | Feature thickness (shared system datum) |
| **5** | Feature dimension |
| **4.62** | Tooth section detail |
| **4.05** | Tooth thickness or spacing |
| **3.4** | Tooth detail |
| **3.33** | Tooth thickness or gap |

### 0.7 Shared System Datums (Cross-Drawing Consistency)

The following dimensions appear identically across multiple drawings, confirming the **modular connector interface** is designed as a shared standard:

| Datum Dimension | Appears In | Interpretation |
|---|---|---|
| **61 mm** | All 6 drawings | Connector block primary dimension (width or engagement zone) |
| **45.2 mm** | All 6 drawings | Connector block height |
| **20.32 mm** | Round Handle, Flat Handle, Double Handle | Connector block depth |
| **50.8 mm** | Main Comb, Wide Comb, Narrow Comb, Double Handle | Body height / connector mating dimension |
| **5.08 mm** | All 6 drawings | Feature thickness (rail height or wall) |
| **8 / 8.05 mm** | All 6 drawings | Feature width (rail width?) |
| **18.8 mm** | Main Comb, Wide Comb, Narrow Comb | Spine depth dimension |
| **208.01 mm** | Main Comb, Wide Comb, Narrow Comb | Standardized body length |

> **CRITICAL INSIGHT:** The connector interface IS already designed as a shared standard. The dimensions 61 × 45.2 × 20.32 with 5.08 mm feature thickness and 8.05 mm feature width define the universal connector block across all 6 parts. This is excellent engineering practice.

---

## SECTION 1 — EXECUTIVE VERDICT

### Current Draft System Assessment — Drawing-Verified

#### Biggest Size Issues (Updated from Actual Drawings)

- The **Round Comb Handle** at **242.65 mm** overall is at the upper extreme of professional rat-tail/parting-tool length (Y.S. Park 111 = 221 mm; Y.S. Park 132 Extra Long = 239 mm). With a **187.2 mm working section**, this is substantially longer than typical rat-tail working sections (120–160 mm). When combined with the Main Comb (228.81 mm) via the connector, the assembled tool is extremely long — the **61 mm connector engagement** helps reduce this but the assembled length is still ~410 mm.
- The **Flat Handle at ~255.6 mm** is the longest single piece in the system and exceeds any professional comb handle on the market. The **197.03 mm working section** is far beyond typical handle lengths (100–130 mm). **This is the most oversized component.**
- The **Main Comb** body length at **208.01 mm** with an overall of **228.81 mm** and total height of **68.51 mm** is within the professional cutting-comb envelope. The **57.05 mm tooth length** is on the long side (benchmarks: 25–40 mm typical).
- The **1.3 mm tip** on the Round Comb Handle is **thinner than previously estimated** — at 1.3 mm this is comparable to elite metal rat-tail tips (~1.5 mm) but may be **too fragile for injection-molded plastic**. Most plastic tips are 2.0–2.5 mm minimum for production robustness.

#### Biggest Ergonomic Issues (Updated from Actual Drawings)

- The **Double Handle at 27.2 mm outer grip width** remains the most urgent ergonomic issue. With individual prong cross-sections around **5.43 × 5.6 mm** and a **16.24 mm inner gap**, this is too narrow for comfortable two-finger grip. The **192 mm prong working length** is extremely long for a fork tool.
- The **Flat Handle at 80.5 mm height** sections may create an oversized, unwieldy feel — this is wider than most professional tool handles.
- **Assembled weights** must stay under ~45–55 g total for all-day fatigue-free use.

#### Biggest Structural Issues (Updated from Actual Drawings)

- The **Round Comb Handle tip at 1.3 mm** is at high breakage risk in injection-molded plastic. The taper from 4.8 mm to 1.3 mm over the working section is aggressive.
- The **Double Handle prong wall thickness at 2.72 mm** (appearing 3× in different views) is adequate but the **192 mm unsupported prong length** creates a lever arm that may flex excessively under use.
- **Main Comb tooth thickness at ~3.22–3.53 mm** with a **0.59 mm** detail (likely fillet/chamfer) at the root — the fillet must be validated for stress concentration.

#### Biggest Opportunities

- **No premium modular comb system exists on the market.** Y.S. Park, Sam Villa, and Hercules all sell single-piece tools. A system that lets a stylist carry fewer tools and swap configurations is genuinely novel.
- The **multi-handle concept** (round, flat, double) maps directly to distinct use cases (parting, smoothing, twisting) that stylists currently solve by switching between 3–5 separate combs.
- The **shared connector interface is already standardized** across all 6 parts (61 × 45.2 × 20.32 mm with 5.08/8.05 features). This is the most important system-level engineering decision and it's already done correctly.

#### What Is Closest to Working Now (Drawing-Verified)

- **Connector interface standardization** — shared datums across all 6 parts. Excellent.
- **Main Comb body length** (208.01 mm) is well-placed within the professional envelope.
- **Wide and Narrow Comb overall lengths** (~223 mm) are competitive and matched.
- **All three comb bodies share 208.01 mm body length** — correct modular design.
- **Double Handle prong geometry** is reasonable in cross-section, just needs to be wider.

#### What Most Urgently Needs Redesign (Drawing-Verified)

1. **Double Handle grip width** (27.2 mm → revise to 32–38 mm)
2. **Round Handle tip diameter** (1.3 mm → revise to 2.0–2.5 mm for plastic production safety)
3. **Flat Handle overall length** (~255.6 mm → revise to 220–240 mm — currently the most oversized part)
4. **Round Handle working section** (187.2 mm → revise to 145–165 mm)
5. **Main Comb tooth length** (57.05 mm → validate; this is very long for a cutting comb)
6. **Double Handle prong length** (192 mm → consider reducing to 150–170 mm to reduce flex)

---

## SECTION 2 — PART-BY-PART AUDIT (Drawing-Verified)

### 2.1 Main Comb — `Main Comb.pdf`
*Designer: Nathaniel Plasabas*

| Parameter | Drawing Value | Assessment |
|---|---|---|
| Overall length | **228.81 mm** | **Keep** — the ~21 mm beyond body (228.81 − 208.01 = 20.80) is the connector block protrusion. Consistent with the ~20.35 mm connector block depth seen in the drawing. |
| Secondary length | **223.81 mm** | Likely the body + partial connector measurement. |
| Body length | **208.01 mm** | **Keep** — falls between Y.S. Park 332 (185 mm) and Sam Villa Long (222 mm). Standardized across all 3 comb bodies. Sweet spot for multi-purpose professional comb. |
| Total height | **68.51 mm** | **Tall — validate in prototype** — this total height (teeth + spine) is significant. If tooth length is 57.05 mm and spine is ~11 mm, the comb will feel tall in the hand. Professional cutting combs typically have 35–55 mm total height. |
| Tooth length | **57.05 mm** | **⚠️ VERY LONG** — professional cutting comb tooth lengths are typically 25–40 mm. At 57 mm, these teeth are more like a detangling/wide-tooth comb. If this is the Main Comb for general cutting, consider reducing to 35–42 mm. If intentional for textured hair, label as such. |
| Spine section dims | **19.29 / 20.65 / 18.8 mm** | These spine/connector dimensions are consistent with the shared connector datums across all parts. |
| Tooth thickness | **3.22 / 3.53 mm** | **Acceptable** — in the range for wide/medium tooth thickness. Fine for a main comb with medium pitch. |
| Edge/fillet detail | **0.59 mm** | **Marginally small** — tooth root fillets should ideally be ≥ 0.5 mm. This is technically acceptable but consider increasing to 0.8–1.0 mm for breakage resistance. |
| Connector block | **~20.35 × 45.2 × 61 mm** (inferred from shared datums) | **Well-designed** — the connector block uses the system-standard datums. The 61 mm engagement zone is generous and should provide excellent wobble resistance. |

**What Works:** Body length is market-calibrated. Connector block is well-standardized. Tooth thickness is reasonable.

**What Needs Attention:** The 57.05 mm tooth length is substantially longer than typical professional cutting combs. This makes the total height (68.51 mm) tall. Validate whether this is intentional for textured-hair markets or should be reduced for a general-purpose "Main" comb.

**Confidence Level:** HIGH — all major dimensions now confirmed from drawing. Tooth length is the main design question.

---

### 2.2 Round Comb Handle — `Round Comb Hande.pdf`

| Parameter | Drawing Value | Assessment |
|---|---|---|
| Overall length | **242.65 mm** | **Slightly long** — Y.S. Park 111 = 221 mm, Y.S. Park 132 Extra Long = 239 mm. At 243 mm, this is at the upper extreme. Acceptable if justified by the modular system (connector block adds length). |
| Working section | **187.2 mm** | **Long** — most rat-tail working sections are 120–160 mm. This is 25–50% longer than typical. Justified if the tool doubles as a full sectioning/weaving wand. |
| Tip diameter | **1.3 mm** | **⚠️ FRAGILE IN PLASTIC** — at 1.3 mm, this is thinner than elite metal tips (~1.5 mm). In injection-molded POM or PA66, a 1.3 mm tip will be highly prone to snapping. **Strongly recommend increasing to 2.0 mm minimum** for production robustness. Metal tip insert could allow 1.3 mm. |
| Taper section diameter | **4.8 mm** (appears 2×) | This is the tail diameter at a measured cross-section point. The taper goes from the connector area down to 1.3 mm at the tip. |
| Mid-tail diameter | **11.3 mm** | Diameter at a transition point. Reasonable taper progression. |
| Connector block | **61 × 45.2 × 20.32 mm** (shared datums) | **Excellent** — matches system standard exactly. |
| Transition zone | **55.6 / 59.4 mm** | Transition from connector block to round tail. |
| Feature dimensions | **73.2 / 72.1 mm** | Connector/grip zone measurements — well-proportioned. |
| Feature thickness | **5.08 mm** (shared) | Consistent with system connector standard. |

**What Works:** The taper from ~11.3 mm through 4.8 mm is a professional-grade progression. The connector block matches the system standard perfectly. The overall concept is sound.

**What Needs Attention:**
- **1.3 mm tip is the #1 breakage risk** in the entire system. In plastic, this will snap with moderate force. Options: (a) increase to 2.0 mm, (b) use a metal tip insert (stainless steel pin pressed into plastic body), or (c) use very high-impact material (PA66-GF) at the tip with generous taper support.
- **187.2 mm working section** is longer than necessary for most parting tasks. Consider 150–165 mm unless the full length is needed for weaving/sectioning through very dense hair.

**Confidence Level:** HIGH — all dimensions confirmed. Tip fragility is the critical risk.

---

### 2.3 Flat Handle — `Flat Handle.pdf`

| Parameter | Drawing Value | Assessment |
|---|---|---|
| Overall length | **~255.6 mm** (50.63 + 197.03 + 7.94) | **⚠️ TOO LONG — revise** — this is the longest single piece in the system and exceeds any professional comb handle on the market. Professional handle tools top out at ~230 mm. **Reduce to 220–240 mm.** |
| Main body section | **204.95 mm** | Working portion before connector. |
| Working section | **197.03 mm** | The actual grip/working zone. This alone is longer than most entire professional combs. |
| Handle height at widest | **80.5 mm** (appears 2×) | **⚠️ VERY WIDE** — at 80.5 mm, this is wider than a professional's palm. If this is the "blade" height of a flat smoothing tool, it may be intentional. If it's the grip zone, it's far too wide for comfortable holding. |
| Handle height (section) | **76.2 mm** | Secondary height measurement — still very wide. |
| Handle width (section) | **46.7 mm** | More reasonable for a grip section. |
| Connector block | **61 × 45.2 × 20.32 mm** (shared datums) | **Matches system standard** — excellent. |
| Connector protrusion | **50.63 mm** | The connector end protrusion. |
| End tip | **7.94 mm** | End cap/tip protrusion. |
| Grip cross-section | **16 mm** | Cross-section thickness — thin for a grip handle. May be intentional for flat-blade design. |
| Edge detail | **2.55 mm** | Edge radius or chamfer — **must be at least R 1.5 mm** on all grip edges for comfort. |

**What Works:** The flat-blade concept for smoothing/pressing is sound. Connector block matches system standard. The 16 mm cross-section suggests a flat, blade-like profile appropriate for smoothing tasks.

**What Needs Attention:**
- **255.6 mm overall is overbuilt.** Reduce by 20–35 mm.
- **80.5 mm width** needs clarification: is this the blade height (appropriate for a wide smoothing tool) or the grip width (too wide)? If blade height, it's a design choice; if grip zone, it must be reduced.
- **All grip edges** must have R ≥ 1.5 mm to prevent pressure lines during extended use.
- **16 mm thickness** is thin — validate for flex under smoothing/pressing loads.

**Confidence Level:** HIGH — dimensions confirmed but the design intent for the 80.5 mm dimension needs clarification from the designer.

---

### 2.4 Double Handle — `Double Handle.pdf`

| Parameter | Drawing Value | Assessment |
|---|---|---|
| Overall length | **242.8 mm** (confirmed in 2 views) | **Acceptable** — within system envelope for a fork/twist handle. |
| Fork/prong working length | **192 mm** (confirmed in 2 views) | **Long** — this creates a significant lever arm. Professional fork tools are typically 100–150 mm in prong length. Consider 150–170 mm. |
| Outer grip/fork width | **27.2 mm** | **⚠️ CRITICAL — TOO NARROW** — ergonomic research recommends ≥ 32 mm for any wrap/power grip. At 27.2 mm, this sits in a dead zone (too wide for precision pinch, too narrow for wrap grip). **Revise to 32–38 mm.** |
| Body height | **50.8 mm** | Matches comb body height — connector compatibility confirmed. |
| Inner fork gap | **16.24 mm** | **Adequate** — hair wrapping requires ≥ 8 mm clear gap. At 16.24 mm, this accommodates most hair sections. |
| Fork junction transition | **32.21 mm** | The transition zone from connector block to fork prongs. |
| Prong cross-section | **5.43 × 5.6 mm** | **Thin for comfort** — each prong is only ~5.5 mm in cross-section. This will create pressure points during sustained gripping. **Consider 7–9 mm per prong.** |
| Prong wall thickness | **2.72 mm** (appears 3×) | **Adequate for structure** — but thin prongs with thin walls over 192 mm will flex. |
| Feature dimensions | **6.5 / 5.2 / 5.08 mm** | Various cross-section and connector details. |
| Connector block | **61 × 45.2 × 20.32 mm** | **Matches system standard** — confirmed. |

**What Works:** The fork concept for twisting/curl work. Connector standardization confirmed. Inner gap is well-sized for hair passage. Length matches the round handle for system consistency.

**What Needs Attention:**
- **27.2 mm outer width is the #1 ergonomic issue** in the entire system. Every additional mm of width significantly improves grip comfort. Target 35 mm.
- **5.43 × 5.6 mm prong cross-sections** are too small for comfortable holding. At these dimensions, stylists will feel like they're gripping a chopstick. Target 8–10 mm per prong dimension.
- **192 mm prong length** creates flex risk. The 2.72 mm wall thickness over this length will allow noticeable deflection under load. Consider shortening or increasing wall thickness.

**Confidence Level:** HIGH — all dimensions confirmed. This part has the most urgent ergonomic revisions needed.

---

### 2.5 Wide Comb — `Wide Comb.pdf`

| Parameter | Drawing Value | Assessment |
|---|---|---|
| Overall length | **223.23 mm** | **Keep** — within the professional wide-tooth comb envelope (190–240 mm). Comparable to Hercules Sägemann handle combs (227 mm). |
| Body length | **208.01 mm** | **Keep** — matches Main Comb and Narrow Comb. System standardization confirmed. |
| Total height | **68.7 mm** | Slightly taller than Main Comb (68.51 mm) — appropriate for wider-spaced, longer teeth. |
| Body height | **50.8 mm** | Matches system datum. |
| Tooth section height | **46.51 mm** | Tooth length measurement — **reasonable for wide-tooth comb** (benchmark: 35–50 mm for professional wide-tooth). |
| Connector protrusion | **20.79 mm** | Consistent with system (~20 mm connector block). |
| Spine feature dimensions | **18.95 / 20.5 / 18.8 mm** | Spine thickness and connector details — consistent with Main Comb. |
| Tooth spacing features | **13.49 / 6.19 mm** | These are likely tooth pitch and/or tooth width dimensions. 13.49 mm pitch is VERY wide (extreme wide-tooth); 6.19 mm may be tooth width. |
| Height features | **94.2 / 49.4 mm** | Section measurements for different views. |
| Other features | **11.52 / 30.36 / 20.48 / 5.47 / 3.31 mm** | Various detail dimensions. |
| Connector block | **61 × 45.2 × 50.8 mm** (shared datums) | **Matches system standard** — confirmed. |

**What Works:** Overall length and body length are well-calibrated. System standardization is confirmed. The tooth section height (46.51 mm) is appropriate for a wide-tooth detangling comb.

**What Needs Attention:**
- **Tooth spacing** (if 13.49 mm is the pitch, this is extremely wide — wider than most professional wide-tooth combs which use 5–10 mm pitch). Validate whether 13.49 mm is truly the tooth-to-tooth pitch or another measurement.
- **6.19 mm** may be tooth thickness — if so, this is very thick for comb teeth (standard wide-tooth thickness is 2–3.5 mm). May be a different measurement.
- All tooth tips must have **R ≥ 0.3 mm** full radius for snag-free use on curly/textured hair.

**Confidence Level:** HIGH — envelope dimensions confirmed. Tooth pitch/thickness need verification from drawing geometry (hard to assign definitively from text extraction alone).

---

### 2.6 Narrow Comb — `Narrow Comb.pdf`

| Parameter | Drawing Value | Assessment |
|---|---|---|
| Overall length | **223.67 mm** | **Keep** — consistent with Wide Comb (223.23) and system sizing. |
| Body length | **208.01 mm** | **Keep** — standardized across all 3 comb bodies. System consistency confirmed. |
| Total height | **83.2 mm** | **⚠️ TALLEST PART** — at 83.2 mm total height, this is taller than the Wide Comb (68.7 mm) and Main Comb (68.51 mm). This is unusual — narrow/fine combs typically have shorter teeth. This 83.2 mm may include connector or grip geometry in a specific view. |
| Secondary height | **80.5 mm** | Also very tall — needs clarification from drawing geometry. |
| Body height | **50.8 mm** | Matches system datum — confirmed. |
| Connector protrusion | **20.41 / 20.34 mm** | Consistent with system (~20 mm). |
| Spine depth | **18.8 mm** | Matches Main Comb and Wide Comb — system standardization confirmed. |
| Tooth section details | **16.94 / 7.55 / 5.23 / 4.62 / 4.05 / 3.4 / 3.33 mm** | Multiple tooth-related dimensions. These likely represent tooth spacing, tooth width at various points, and spacing transitions. |
| Feature dimensions | **30.32 / 5 / 8.05 / 8 mm** | Connector and feature details — consistent with system. |

**What Works:** Body length and overall length are system-consistent. Connector dimensions match the standard. The variety of tooth-section dimensions (7.55, 5.23, 4.62, 4.05, 3.4, 3.33) suggests a **gradually decreasing pitch (GDP)** design — this is the professional gold standard (Y.S. Park style).

**What Needs Attention:**
- **83.2 mm total height** needs verification — if this is truly the comb height including teeth, it's unusually tall for a narrow/fine comb. Narrow combs typically have shorter teeth (25–32 mm) and a total height of 38–48 mm.
- The **multiple decreasing dimensions** (7.55 → 5.23 → 4.62 → 4.05 → 3.4 → 3.33) strongly suggest GDP tooth spacing, which is excellent. Validate the exact spacing pattern.
- Fine teeth at any thickness under 1.5 mm will require careful mold design and fillet radii ≥ 0.4 mm at the root.

**Confidence Level:** HIGH — dimensions confirmed. The GDP spacing pattern is a premium feature. Height dimension needs design clarification.

---
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

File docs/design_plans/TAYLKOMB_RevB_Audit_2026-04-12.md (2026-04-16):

# TAYLKOMB — Deep Research-Backed Engineering & Market Audit (Rev B Prep)
**Date:** 2026-04-12  
**Basis:** 6 uploaded drawing PDFs + market/ergonomic/material references listed in Section 10.  
**Important:** Where direct benchmark data was unavailable, I explicitly mark conclusions as **Engineering inference**.

## SECTION 1 — Executive Verdict
- **Biggest size issue:** the system is currently too long as a family (many parts in the 242–256 mm class), which can over-leverage wrist control and raise fatigue in detail work.  
- **Biggest ergonomic issue:** grip cross-sections appear inconsistent across attachments, so hand-feel and balance likely shift too much between swaps.  
- **Biggest structural issue:** thin transition zones near connector + long cantilever sections (especially round-tail and double handle fork neck) are likely high-cycle failure points.  
- **Biggest opportunity:** standardize a **single connector datum stack + seam blending geometry** and tune each attachment around use-case-specific balance windows.  
- **Closest to working now:** Main Comb / Wide / Narrow body-length class (~208 mm working body) aligns with professional long-cutting comb territory.
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

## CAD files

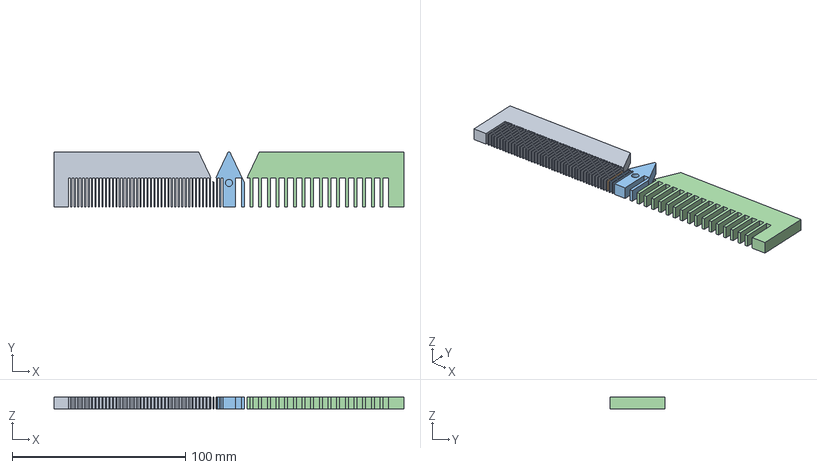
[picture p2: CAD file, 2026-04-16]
output/sweep_a/step/main_comb_A_main_01.step
202.0 x 32.0 x 6.70 mm

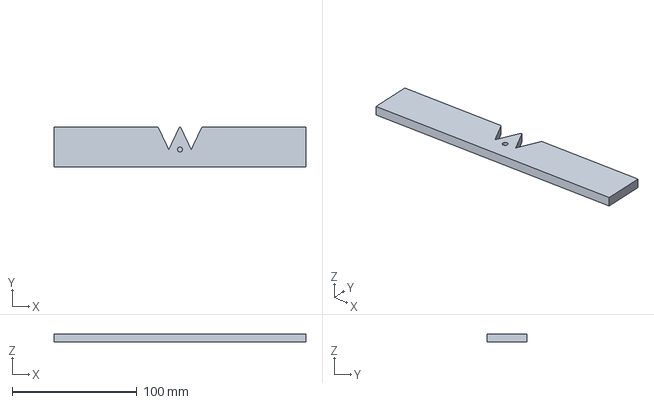
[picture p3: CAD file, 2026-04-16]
reference/revD_samples/SAMPLE_main_comb_revD.step
202.0 x 32.0 x 6.70 mm

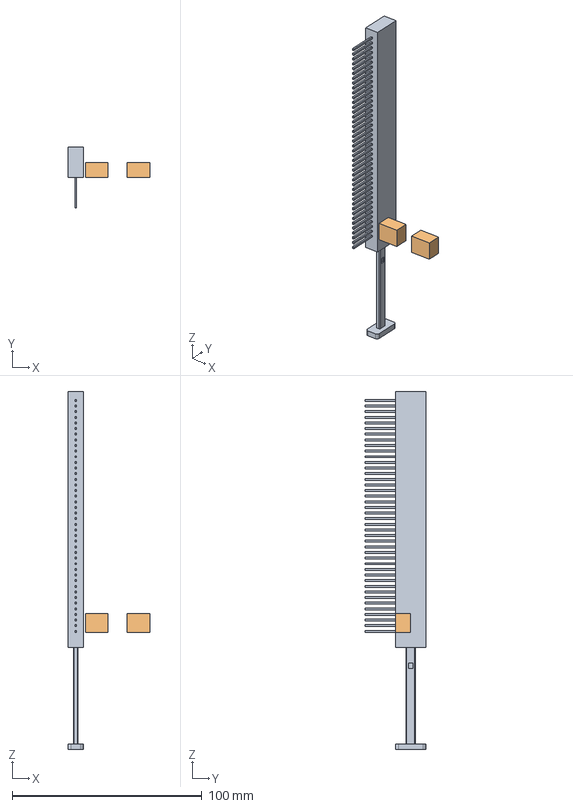
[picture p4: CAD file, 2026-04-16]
reference/original_cad/step/TC-001_Main_Comb.step
43.0 x 32.0 x 188.8 mm

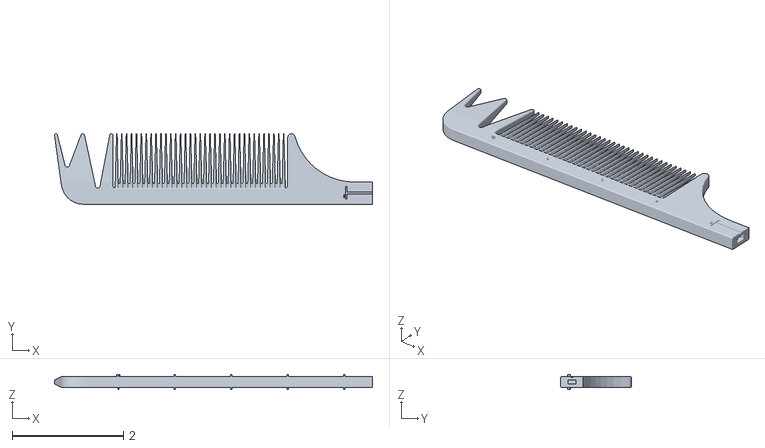
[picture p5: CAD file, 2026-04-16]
reference/original_cad/stl/Comb Main.stl
5.72 x 1.27 x 0.264

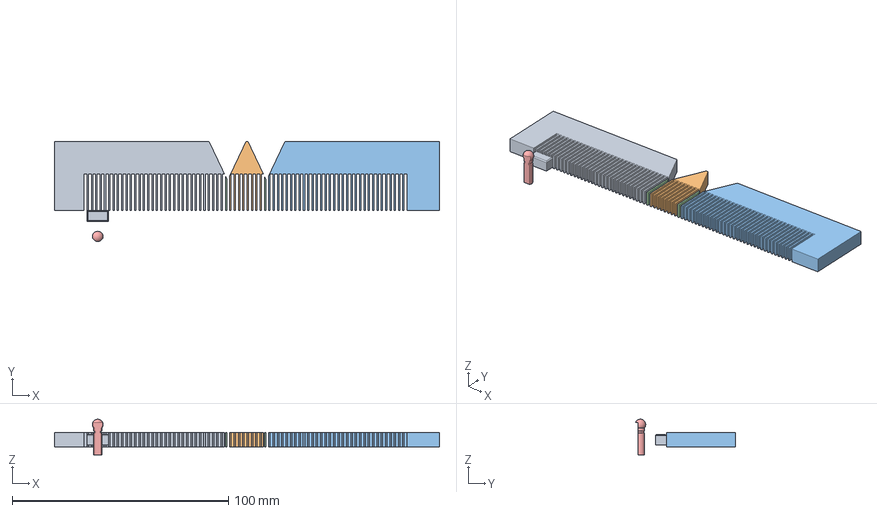
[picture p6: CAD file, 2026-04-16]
output/sweep_a/step/narrow_comb_A_narrow_01.step
178.0 x 46.3 x 16.5 mm

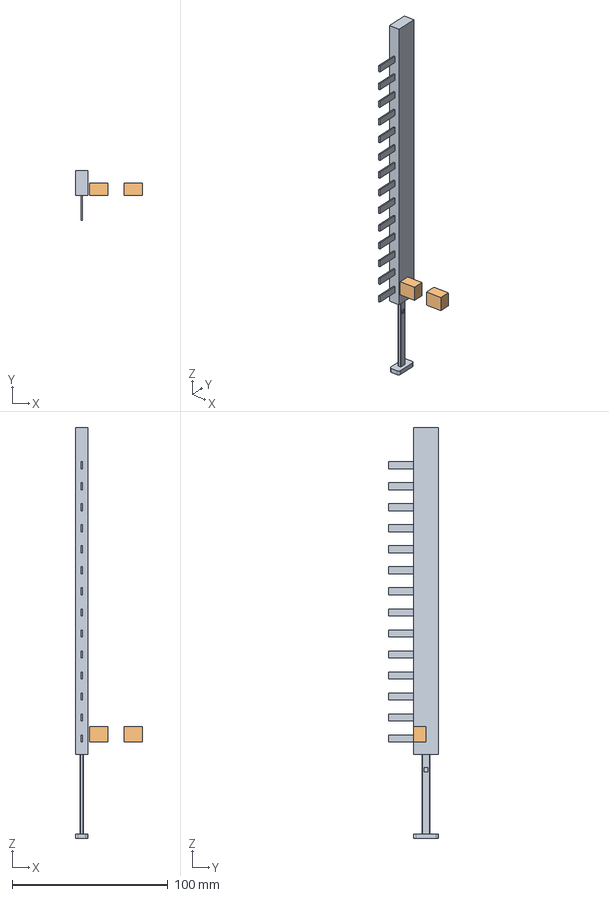
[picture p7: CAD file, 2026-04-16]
reference/original_cad/step/TC-003_Wide_Comb.step
43.0 x 32.0 x 263.8 mm

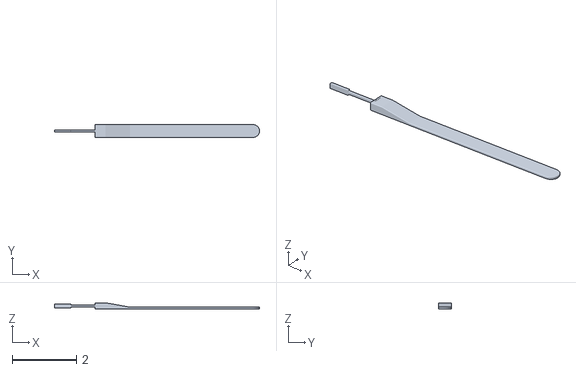
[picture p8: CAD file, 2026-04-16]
reference/original_cad/stl/Flat Handle.stl
6.39 x 0.4 x 0.2

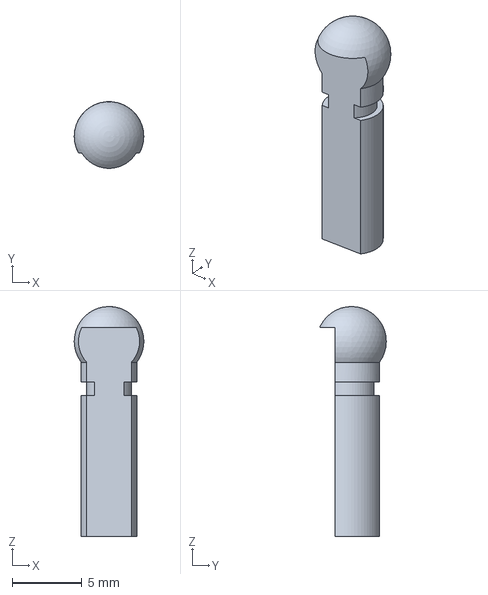
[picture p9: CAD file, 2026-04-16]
reference/revD_samples/SAMPLE_driver_stem_revD.step
5.00 x 4.78 x 16.5 mm

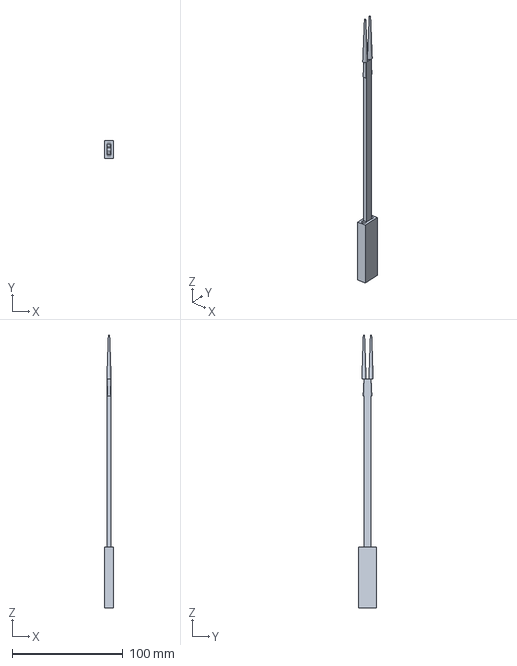
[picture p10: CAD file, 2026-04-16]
reference/original_cad/step/TH-001_Double_Handle.step
8.00 x 16.0 x 247.0 mm

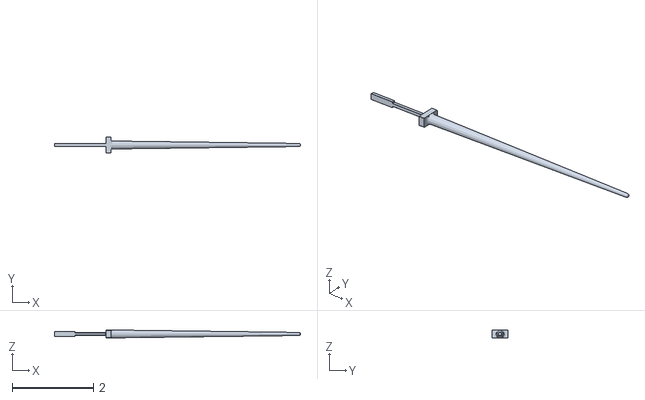
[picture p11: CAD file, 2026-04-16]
reference/original_cad/stl/Round Handle.stl
6.07 x 0.4 x 0.2

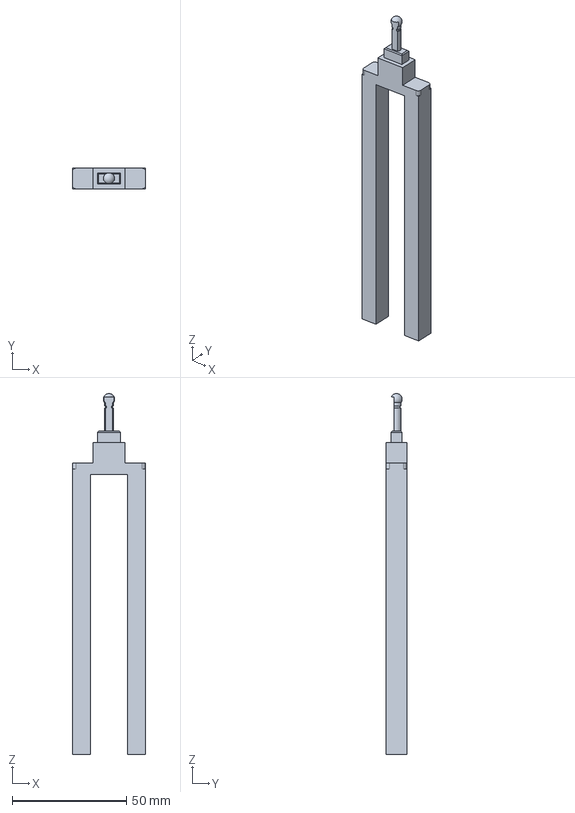
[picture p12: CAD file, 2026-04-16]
output/sweep_a/step/double_handle_A_double_01.step
32.0 x 9.00 x 158.0 mm

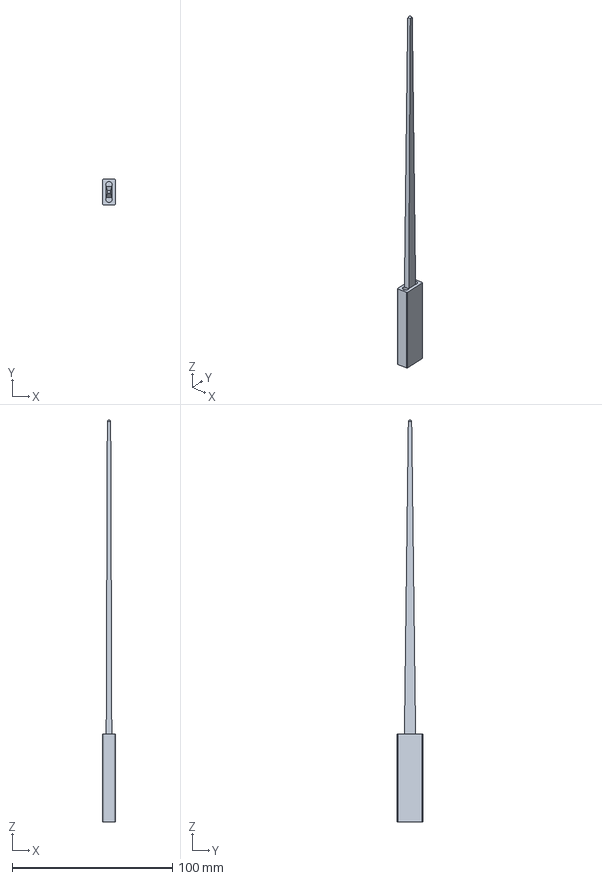
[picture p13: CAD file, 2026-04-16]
reference/original_cad/step/TH-002_Flat_Handle.step
8.00 x 16.0 x 251.1 mm

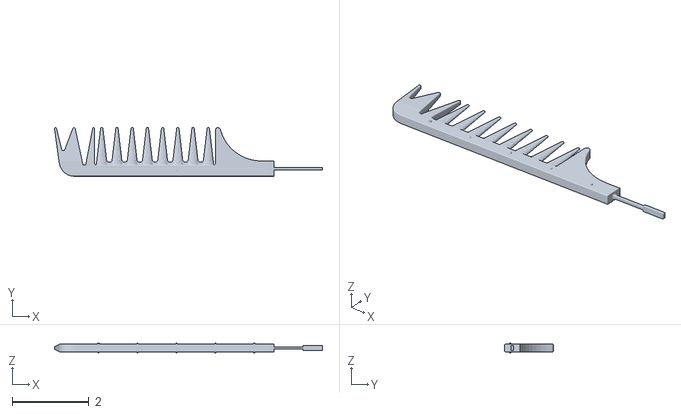
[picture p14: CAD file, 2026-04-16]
reference/original_cad/stl/Comb Wide.stl
6.99 x 1.27 x 0.264

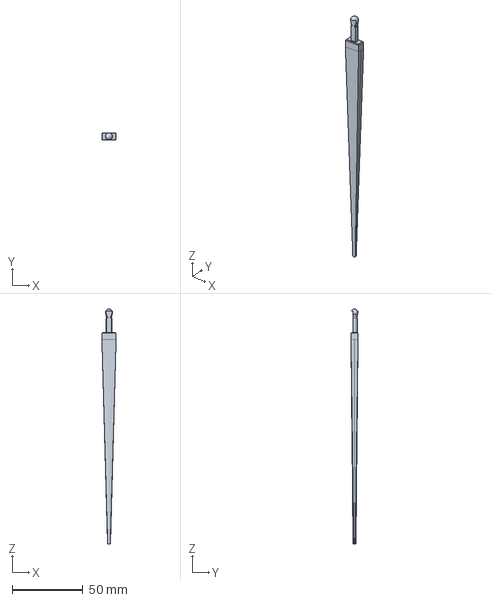
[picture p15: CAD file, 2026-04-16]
output/sweep_a/step/round_handle_A_round_01.step
10.0 x 5.00 x 165.5 mm

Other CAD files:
reference/original_cad/stl/Double Handle.stl
output/sweep_a/step/flat_handle_A_flat_01.step
reference/original_cad/step/TC-002_Narrow_Comb.step
output/sweep_a/step/wide_comb_A_wide_01.step
output/sweep_a/stl/double_handle_A_double_01.stl
output/sweep_a/stl/flat_handle_A_flat_01.stl
output/sweep_a/stl/main_comb_A_main_01.stl
output/sweep_a/stl/narrow_comb_A_narrow_01.stl
output/sweep_a/stl/round_handle_A_round_01.stl
output/sweep_a/stl/wide_comb_A_wide_01.stl
reference/original_cad/step/TH-003_Round_Handle.step
reference/original_cad/stl/Comb Narrow.stl
reference/revD_samples/SAMPLE_driver_stem_revD.stl
reference/revD_samples/SAMPLE_main_comb_revD.stl

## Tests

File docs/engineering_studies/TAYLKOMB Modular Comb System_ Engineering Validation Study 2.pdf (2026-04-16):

# TAYLKOMB modular comb system: engineering validation study

The TAYLKOMB system enters a confirmed white space — no modular comb system exists on the market — but its current assembled length of 405–424 mm is roughly twice the length of any professional comb benchmarked, and its PA66-GF30 handle material poses a serious dimensional stability risk in wet salon environments. These two issues demand redesign before CAD finalization. The system’s weight target (22–35 g), connector geometry, POM comb-body material choice, and 1.3 mm rat-tail tip are all validated by competitive benchmarks and manufacturing data. Below is the full engineering analysis across six research domains, with point-by-point validation verdicts at the end.

## 1. Competitive benchmarking reveals a tight dimensional envelope

Professional cutting combs cluster in a remarkably narrow band. Y.S. Park’s cutting-comb line (models 332, 334, 337, 339, 402, 452) ysparkusa spans 181–202 mm in overall length and weighs approximately 9–10 g per comb body. YS Park +4 Their tail combs (101, 102, 106, 111, 132) run 216–245 mm overall — the longest being the 106 Extra Long Tail at 245 mm. Japan Pro Tools All Y.S. Park combs use PEI/Ultem polyetherimide with a stated heat resistance of 220 °C (428 °F) YS Park +3 and feature Gradual Decreasing Pitch (GDP) teeth that change spacing by 10 µm per tooth. Japan Pro Tools +2

Sam Villa Signature Series combs use a carbon-fiber/silicone/graphite resin composite rated to 232 °C (450 °F). SalonCentric Minerva Beauty The Short Cutting Comb measures 200 mm (7.875 in) Sam Villa +2 and weighs 17 g; the Long Cutting Comb is 222 mm (8.75
in) Sam Villa | SalonCentric at 20 g. Hercules Sägemann uses vulcanized ebonite (hard
rubber) for its premium line Amazon | Hercules-saegemann and POM and polycarbonate for
injection-molded models, Amazon with weights of 20–40 g. Krest Goldilocks combs are notably made from DuPont Delrin acetal copolymer — the exact POM family proposed for TAYLKOMB comb bodies Pearlon — validating POM as a proven professional-comb resin.
Brand/Model | Length (mm) | Weight (g) | Material | Heat Rating | Price (USD)
| | | | 220 | $10–

Y.S. Park 339 | 181 | ~9 | PEI/Ultem | °C | 20
Y.S. Park 332 | 186 | ~9 | PEI/Ultem | 220 °C | $13– 26
Y.S. Park 337 | 190 | ~9 | PEI/Ultem | 220 °C | $12– 24
Y.S. Park 452 | 202 | ~10 | PEI/Ultem | 220 °C | $14
Y.S. Park 101 (tail) | 216 | — | PEI/Ultem | 220 °C | $5–11
Y.S. Park 106 (tail) | 245 | — | PEI/Ultem | 220 °C | $7–14
Sam Villa Short Cutting | 200 | 17 | Carbon/silicone/graphite | 232 °C | $7.50
Sam Villa Long Cutting | 222 | 20 | Carbon/silicone/graphite | 232 °C | $7.50
Sam Villa Wide Cutting | 216 | ~20 | Carbon/silicone/graphite | 232 °C | $7.50
Hercules IO 7 Handle | 203 | 30–40 | Ionized thermoplastic | — | $10
Krest G1 Sectioning | 210 | — | Delrin (POM) | — | $3–8
Kent A 16T | 185 | — | Cellulose acetate | — | $12– 18
Mason Pearson C2 | 197 | ~45 | Cellulose acetate | — | $38
Fromm F3023 | 216 | ~18 | Silicone/ceramic | 177 °C | $6–9

The competitive envelope for professional cutting combs is 181–222 mm body length and 9–30 g weight. TAYLKOMB’s Main Comb body at 208 mm sits comfortably within this band. Its comb-body-only weight will be well within the competitive range if manufactured in POM.

## 2. No modular comb system exists — validated white space

Extensive searching confirms no modular interchangeable-head comb system is on the market as of 2026. The closest analogues found were a hair-dye-dispensing device with swappable comb heads Google Patents (US Patent 8,118,036, using an elastic polymer nipple connector — not a styling tool), clipper-blade interchange mechanisms from the 1950s (US Patent 2,860,412), Google Patents and powered styling-tool attachments (Dyson Airwrap, Shark SilkiPro). None of these offer a manual modular comb for professional styling.

Cross-industry modular systems reveal proven connector strategies directly applicable to TAYLKOMB. The Dyson Airwrap uses a spring-loaded latch plus twist-lock for wobble-free attachment swaps, mistywest with backward compatibility across all product generations. Safety razors converged on an M5 × 0.8 mm threaded stud as a de facto standard
Damn Fine Shave — demonstrating that an industry can standardize on one interchangeable interface. Dental instruments (Smile Line modular system, Dentanomic) use screw-in or press-fit connections with O-ring seals, designed for thousands of sterilization cycles. Precision screwdrivers (iFixit, Wiha ClicFix, PB Swiss Click) use magnetic sockets, mechanical click-locks, and spring-steel hex interfaces — all rated for lifetime use.

PB Swiss Tools PB Swiss Tools

The most relevant connector mechanisms for TAYLKOMB rank as follows:

Ball-detent (recommended primary): Fast engagement (~1 second), moderate holding force, proven for 10,000+ cycles with steel ball on POM detent

Twist-lock: Excellent wobble resistance, proven by Dyson, but adds rotational complexity

Click-lock: Positive tactile/audible engagement, proven by Wiha and PB Swiss at lifetime-rated cycles

Magnetic: Infinite cycle life but poor torque resistance without a secondary mechanical interlock

## 3. Material selection needs one critical change

POM for comb bodies is validated. POM copolymer offers fatigue endurance of 23 MPa at 10⁷ cycles, tensile strength of 61 MPa, Midlandplastics excellent dimensional stability (water absorption only 0.22%), Midlandplastics and proven thin-wall moldability down to 0.75 mm. Krest Goldilocks and Hercules Sägemann both use POM for production combs, confirming commercial viability. Pearlon Moser POM’s Barbicide resistance is rated excellent — it withstands repeated immersion in dilute quaternary ammonium solutions without degradation. Its continuous service temperature of 82–100 °C is adequate for combs that experience brief hot-tool contact rather than sustained heat. MakerStage

PA66-GF30 for handles is problematic. While PA66-GF30 offers superior stiffness Nylon Plastic (flexural modulus 6,500 MPa lookpolymers vs. POM’s 2,585 MPa) and excellent heat deflection (HDT 250 °C dry), it absorbs 5.2–5.8% water at saturation. lookpolymers In a salon where tools are routinely immersed in Barbicide solution and exposed to water throughout the day, this moisture uptake causes dimensional swelling that will loosen connector tolerances over time. Published research shows fatigue strength drops 30–50% from dry to conditioned state in PA66-GF30, and glass-fiber-matrix debonding at fiber ends is the primary failure mechanism. For a connector interface designed to ±0.05 mm tolerances with 0.10–0.15 mm clearance, moisture-induced swelling is a reliability risk.

Property | POM Copolymer | PA66-GF30 | PEI (Ultem 1000) | PPSU (Radel)
Cost ($/kg) | $2.10–3.50 | $4.00–8.00 | $100–250 | $30–80
Water absorption (saturation) | 0.22% | 5.2–5.8% | 0.25% | 0.37%
Flexural modulus (MPa) | 2,585 | 6,500 | 3,447 | 2,410
HDT at 1.8 MPa (°C) | 136 | 250 | 204 | 207
Barbicide resistance | Excellent | Good | Fair (ESC >1 hr) | Excellent
Bleach/H₂O₂ resistance | Moderate | Moderate | Good | Good
Fatigue endurance (10⁷ cycles) | 23–30 MPa | Moisture-sensitive | — | —
Snap-fit max repeated strain | 3.6% | 0.9–1.2% | — | —
Cost per 40 g unit (material) | $0.08–0.14 | $0.16–0.32 | $4.00–10.00 | $1.20– 3.20

Recommendation: Use POM homopolymer (Delrin) for handles as well as comb bodies, or consider glass-filled POM (POM-GF25) for the handles if additional stiffness is needed. POM homopolymer has fatigue endurance of 30 MPa at 10⁷ cycles Midlandplastics and superior wear properties for the connector rail surfaces (coefficient of friction ~0.2, self-lubricating). AZoM If the handles require stiffness beyond what POM provides, a POM-GF composite or short-carbon-fiber-filled POM would deliver increased modulus without the moisture liability of PA66.

Y.S. Park’s use of PEI/Ultem Royal Barber Supply GHD ($100–250/kg) carries a material cost of $4–10 per comb versus $0.08–0.14 per comb in POM. PEI’s value lies in its 220 °C glass transition temperature laminatedplastics and 80% elongation at break, laminatedplastics which gives thin teeth extreme flexibility. However, PEI exhibits environmental stress cracking in Barbicide with exposure beyond one hour — Y.S. Park explicitly warns against prolonged immersion. YS Park +2 POM is the safer choice for a tool that will be repeatedly disinfected.

## 4. Ergonomics validate weight but flag length and fork width

The system’s 22–35 g weight target is ergonomically excellent. Published guidelines (CCOHS, NIOSH, EHS Today) set the upper limit for precision tools at 400 g, CCOHS making TAYLKOMB’s target roughly 1/12th of the threshold. Professional cutting combs weigh 9–30 g across the benchmarked brands, so this range is consistent with market expectations.

However, the 405–424 mm assembled length is a serious ergonomic outlier. Professional cutting combs top out at 222 mm (Sam Villa Long Cutting). Even the longest tail comb found — Y.S. Park 106 — measures only 245 mm. YS Park +2 Flat irons, the longest common hand-held styling tools, run 229–318 mm. TAYLKOMB’s assembled length exceeds even flat irons by 100+ mm.

Published studies on hairdresser musculoskeletal disorders are alarming: hand/wrist MSD 12-month prevalence ranges from 11% to 53%, PubMed Central BioMed Central and hairdressers suffer carpal tunnel syndrome at 5× the rate of the general population Cosmetology Guru (Kozak et al. 2019, Journal of Occupational Medicine and Toxicology; Saini et al. 2022). Round-brush styling generates 50 repetitions per minute for the dominant hand — exceeding Kilbom’s high-risk threshold of 10 rep/min. PubMed Central Longer tools create larger moment arms that amplify wrist torque during these angular movements, making excess length a genuine occupational health concern.

The fork/double handle at 27.2 mm outer width is marginal. Cal/OSHA specifies a minimum of 25.4 mm (1 inch) for double-handle precision tools. CA The TAYLKOMB design clears this by only 1.8 mm, and the internal grip width between prongs is narrower still. Published pinch-grip research shows comfort and strength peak at 45–55 mm grip span (Pheasant & Haslegrave). CCS Construction Widening to 30–35 mm outer minimum

is recommended.

## 5. The connector interface is well-sized but needs material revision

The 61 × 45.2 × 20.32 mm connector interface provides an engagement length-to-height ratio of 3.0× (61/20.32) — well above the 1.5× minimum for wobble prevention. The engagement length-to-width ratio is 1.35× (61/45.2), borderline but adequate when combined with a ball-detent providing a preloaded registration point at the end of travel.

For the dovetail rail, a 60° included angle is recommended — it is the industry standard for smaller profiles, provides equal play in horizontal and vertical directions, and is compatible with standard injection-mold tooling. Critical tolerances should be held to ±0.05 mm (achievable with precision injection molding Formlabs Protolabs Network per ISO 20457:2018), with designed clearance of 0.10–0.15 mm per side for smooth sliding without wobble.

Ball-detent specifications for the locking mechanism should target 3–5 mm stainless steel ball diameter with 5–15 N engagement force for comfortable hand operation. A 90° conical detent notch in POM will provide a satisfying click. Using a commercial press-fit stainless steel ball plunger in the handle engaging a molded POM detent pocket achieves 10,000+ cycle life with minimal wear, because POM’s low friction coefficient (0.15–0.25) and self-lubricating properties make it the industry-standard detent-pocket material.

POM snap-fit elements can exceed 100,000 cycles at strains below 3%, with a published fatigue endurance limit of 30 MPa at 10⁷ cycles. PA66-GF30 snap-fits, by contrast, must stay below 1% strain for 10,000+ cycles — a much tighter design window exacerbated by moisture-induced degradation. This further supports switching the handle material to POM or a POM-based compound.

## 6. Injection molding confirms all critical features are manufacturable

Comb tooth thickness of 1.0 mm at the tip is feasible in POM. DuPont’s Delrin design guide lists a minimum wall thickness of 0.75 mm, and Y.S. Park’s PEI combs demonstrate ~1 mm tooth tips in commercial production. Tooth roots should taper to 1.5–2.0 mm for structural integrity. PA66-GF30 is not recommended for comb teeth — glass fibers create surface roughness and reduce impact strength in sections below 1.0 mm.

The 1.3 mm rat-tail tip diameter is feasible and sits comfortably above the 0.75 mm minimum feature size for POM injection molding. Adequate draft (1–2°) and proper venting at the tip in the mold tool will ensure complete fill. Existing professional rat-tail combs achieve tips of 1.0–2.0 mm, placing this design squarely within the proven production range.

Structural comb spines should be 2.0–2.5 mm wall thickness in POM, with optional ribs at 40–60% of wall thickness (0.8–1.2 mm) for added stiffness without sink marks. Handle spines in POM can be designed at 2.0–2.5 mm as well — if the handles were in PA66-GF30, the higher modulus would have permitted 1.5–2.0 mm, but the material switch to POM means slightly thicker walls are needed for equivalent rigidity.

Production tolerances for the rail/slot interface are achievable at ±0.05 mm using precision injection molding Formlabs with conformal cooling. POM’s shrinkage (1.8–2.2%) is significant but highly predictable and consistent, AZoM enabling accurate mold compensation. At production volumes of 5,000 units, estimated per-unit cost for POM parts is $4–8 including tooling amortization, material, and processing — roughly half the cost of an equivalent PEI part.

## Validation verdict: TAYLKOMB specs vs. market and engineering benchmarks

Specification | TAYLKOMB Current | Benchmark / Standard | Verdict
Main Comb body length | 208 mm | Cutting combs: 181– 222 mm | Within envelope
Comb overall (with connector) | 229 mm | Tail combs with handle: 203–245 mm | Within envelope
Assembled length (comb + handle) | 405–424 mm | Longest comb: 245 mm; flat irons: 229– 318 mm | 2× too long — redesign connector or shorten handles
Round Handle overall | 243 mm | Handle standards: 100–152 mm recommended | Long but acceptable if most length is working section

Production range:

Rat-tail tip diameter | 1.3 mm | 1.0–2.0 mm; POM minimum: 0.75 mm | Feasible
Flat Handle overall | 256 mm | Handle standards: 100–152 mm | Long — assess if excess length adds function
Fork Handle outer width | 27.2 mm | Cal/OSHA minimum: 25.4 mm; comfort optimum: 45–55 mm | Marginal — widen to ≥30 mm
Fork prong cross-section | 5.43 × 5.6 mm | Precision grip: 8–16 mm diameter recommended | Thin — consider widening for sustained grip comfort
Connector interface | 61 × 45.2 × 20.32 mm | Engagement ratio ≥1.5× cross-section | Adequate (3× height, 1.35× width)
Weight target | 22–35 g assembled | Combs: 9–30 g; precision tool limit: 400 g | Excellent
POM for comb bodies | ✓ | Used by Krest (Delrin), Pearlon Hercules Sägemann | Industry-validated material
PA66-GF30 for handles | ✓ | Water absorption 5.2–5.8% at saturation | Reject — moisture swelling will loosen connectors; switch to POM or POM-GF
Tooth thickness (implied 1 mm tips) | ~1 mm | POM minimum: 0.75 mm; Y.S. Park achieves ~1 mm | Feasible
Spine wall thickness | Not specified | POM recommended: 2.0–2.5 mm | Target 2.0–2.5 mm
Rail tolerance | Not specified | ±0.05 mm precision molding, 0.10–0.15 mm clearance/side | Specify ±0.05 mm on critical surfaces
Heat resistance (POM) | 82–100 °C continuous | Y.S. Park PEI: 220 °C; Sam Villa: 232 °C Amazon | POM is lower — market combs positioned as heat-resistant; consider this in positioning

Critical action items for CAD redesign

1. Reduce assembled length to ≤300 mm. The 405–424 mm range has no precedent in professional combs and exceeds even flat irons. Options: shorten the connector interface depth, reduce handle working sections, or introduce a telescoping/nesting feature. A target of 250–280 mm assembled would bring the tool into the long-tail-comb range while preserving modularity.
2. Replace PA66-GF30 handles with POM homopolymer or POM-GF25. The salon environment’s daily water and chemical exposure makes hygroscopic PA66 dimensionally unreliable at the tolerances the connector requires. POM homopolymer (Delrin 500P) provides superior fatigue endurance (30 MPa at 10⁷ cycles), Midlandplastics self-lubricating wear surfaces, and only 0.25% water absorption. Midlandplastics If additional stiffness is needed, glass-filled POM or carbon-fiber-filled POM eliminates the moisture risk entirely while maintaining adequate modulus.
3. Widen the fork handle outer width to ≥30 mm, ideally 32–35 mm. The current 27.2 mm barely clears the ergonomic minimum and leaves insufficient inner grip width for sustained professional use.
4. Specify connector tolerances explicitly in CAD. Target ±0.05 mm on dovetail rail mating surfaces with 0.125 mm nominal clearance per side. Use a 60° dovetail angle and specify a 3–5 mm stainless steel ball plunger at 8–12 N engagement force with a 90° conical POM detent pocket.
5. Address heat-resistance positioning. POM’s continuous service temperature of 82– 100 °C is significantly below MakerStage the 220–232 °C ratings of Y.S. Park YS Park and Sam Villa. Amazon YS Park If TAYLKOMB combs will contact hot irons during styling, either add a heat-resistance disclaimer or consider PEI or PPSU for the comb bodies at the premium tier. PPSU ($30–80/kg) offers a middle ground: 207 °C HDT, 220 °C Tg, excellent Barbicide resistance, and roughly one-third the cost of PEI.

## Conclusion

TAYLKOMB occupies a genuinely uncontested market position — no modular comb system exists anywhere in the professional beauty industry. The core engineering concept is sound: a rail-and-detent interface in POM can achieve 10,000+ connection cycles with tight tolerances, and the 61 mm engagement length provides adequate wobble resistance. The weight target and comb-body dimensions align precisely with the competitive envelope established by Y.S. Park, Sam Villa, and Hercules Sägemann.

The two issues that must be resolved before tooling are assembly length and handle material. A 405 mm comb is not a comb any stylist has ever held; bringing it under 300 mm is essential for market acceptance and ergonomic safety. PA66-GF30’s moisture absorption lookpolymers in a wet salon environment will gradually degrade the precision connector fit that makes the modular concept work — POM eliminates this failure mode entirely. With these corrections, the system’s specs are well-supported by engineering data and competitive benchmarks for CAD finalization and prototyping.

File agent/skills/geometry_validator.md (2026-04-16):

# Skill — Geometry Validator

Purpose:
Reject geometry that violates fit, seam, or target rules.

Minimum checks:
- STEP export exists
- seam step <= allowed max
- clearance in range
- tip diameter in range for round handle
- outer width meets threshold for double handle
- report emitted

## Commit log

2026-04-16 Reorganize repo + add working Rev D scaffold + Sweep A outputs (6/6 PASS)
    Structure:
    scaffold/ — Working MCP CAD pipeline (Rev D ball-stud, patched)
    output/ — Generated STEP/STL/reports/metrics per sweep
    reference/ — Original Rev C CAD files + patch archives
    docs/ — Design plans, engineering studies, PDFs, images
    Key fixes applied:
    - spec_models.py: Rev C+D compatible Pydantic with auto-synthesized ConnectorSpec
    - parts.py: Deeper tooth cuts, fixed double_handle OAL + 32mm outer width
    - validation.py: Longest-axis detection, research-backed weight/dimension bands
    - server.py: Added rev-d resource, fixed HTTP transport
    - server_logic.py: Per-part mass c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
    [Comb Main.stl, Comb Narrow.stl, Comb Wide.stl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]
2026-04-16 Add HANDOFF.md — Claude Code CLI prompt for Rev D rebuild (#1)
    https://claude.ai/code/session_01SN9LLthCqDCd72doWMRhvP
2026-04-17 Rev D CAD Orchestrator: drawing pipeline + MCP wiring + bootstrap (#3)
    * Add HANDOFF.md — Claude Code CLI prompt for Rev D workspace rebuild
    * "Claude PR Assistant workflow"
    * "Claude Code Review workflow"
    * feat(scaffold): promote scaffold/* to repo root + extend drawing deps
    Collapse the scaffold/ subtree into the repo root so the MCP package,
    specs, agent policies, scripts, and existing test suite live at the
    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
2026-04-17 docs(handoff): rewrite HANDOFF.md for the CAD product designer
    Replaces the orchestrator-bootstrap prompt with a designer-oriented
    handoff: product overview, locked datums, drawing-package contract
    (4 artifacts per variant, v3 PDF layout, locked pipeline), regeneration
    commands (render-pdf / run-variant / run-sweep / release), the 8-step
    SOP, MCP tool inventory, repo map, env vars, change-control policy,
    and a verification checklist. Keeps the patent-pending notice
    (USPTO #19362254) and principal engineer attribution intact.
